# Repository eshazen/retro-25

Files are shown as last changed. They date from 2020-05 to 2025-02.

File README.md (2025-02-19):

# retro-25
Retro-tech HP-25 calculator clones using Z80

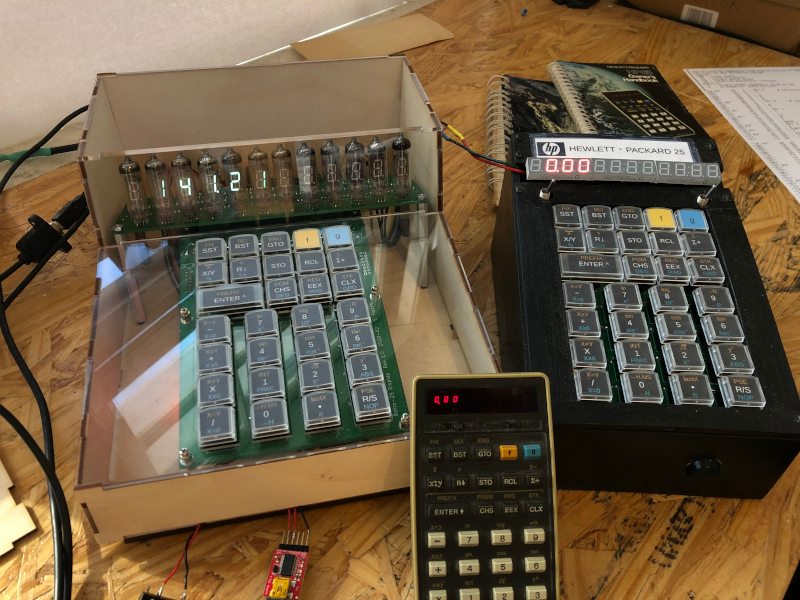
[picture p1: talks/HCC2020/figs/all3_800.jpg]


<table>
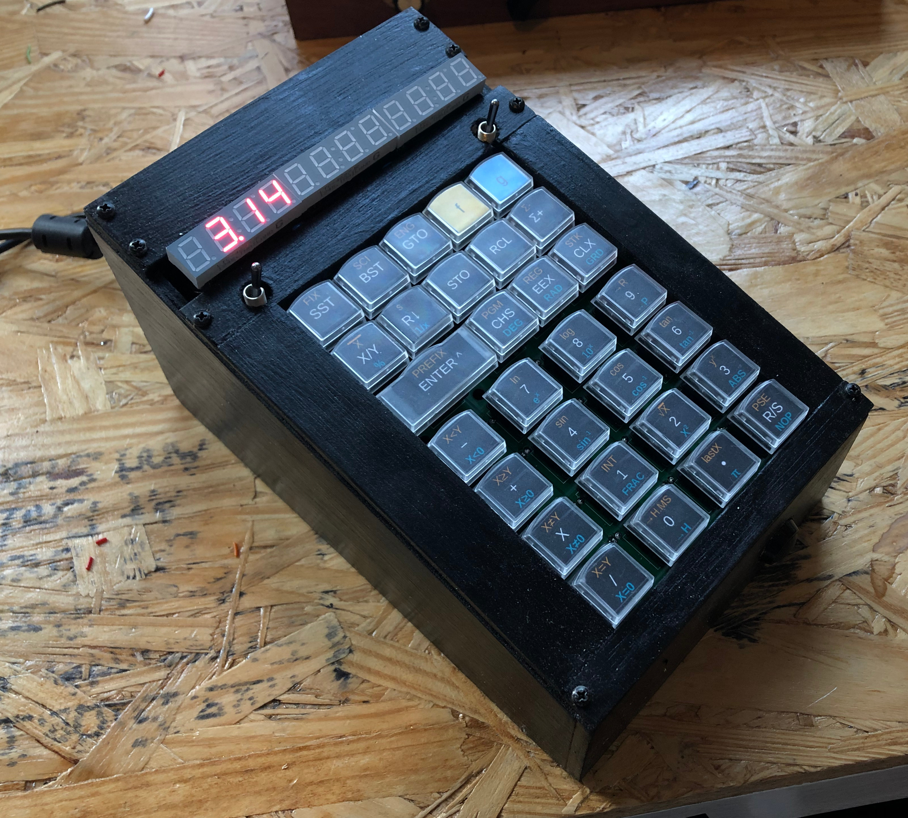
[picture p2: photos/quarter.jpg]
  <tr><td>
      <td>
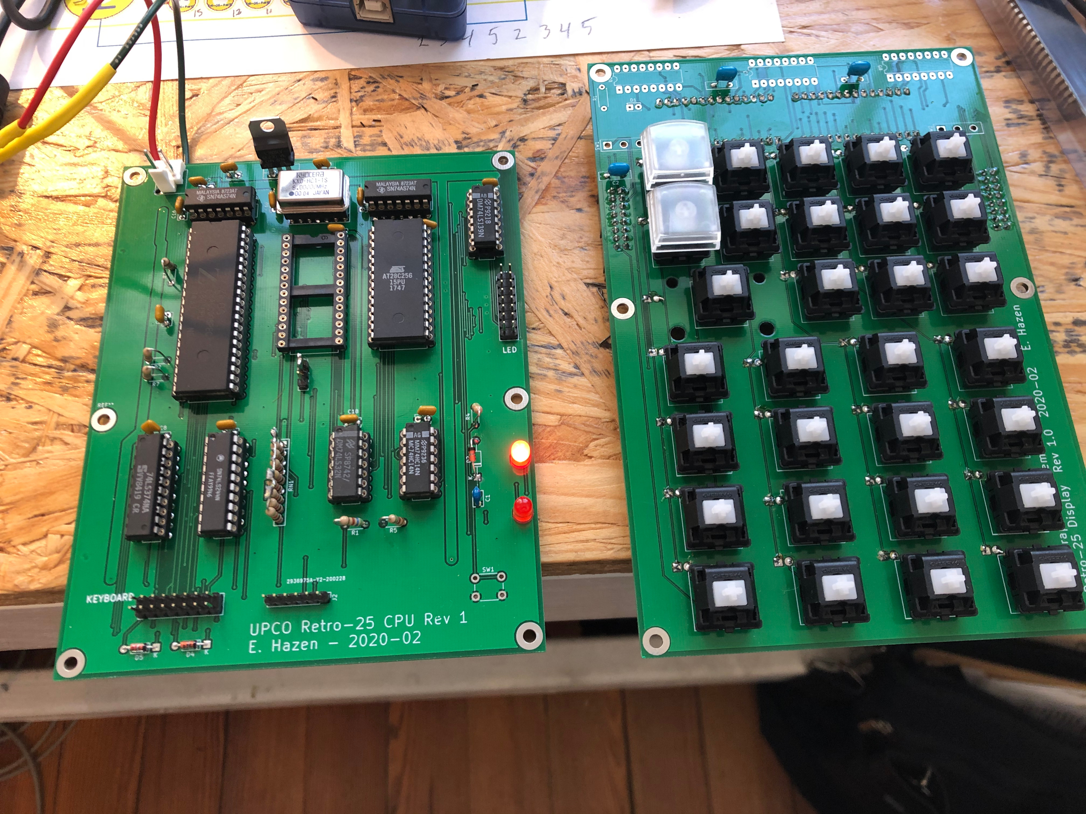
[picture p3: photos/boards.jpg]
      <td>
</table>

## News!

**2023-01-02**

This is **branch "ScopeClock"**.  Building up another CPU board for used as a general purpose computer for the scope clock, along with the DAC/Interface board from that project, which (whew!) has an actual UART for the serial port.

**2021-01-01**

Time for something new!  The VFD HP-25 is cool and all, but I've lusted after an HP-97 most of my life, plus I love nixie tubes!  Starting to think about a nixie-display HP-97 emulator.  Probably no card reader, but a small printer is certainly doable.  Inspiration from Oliver De Smet (archived elswhere in this repository just in case):

* https://www.hpmuseum.org/cgi-sys/cgiwrap/hpmuseum/archv020.cgi?read=204526
* https://sites.google.com/site/olivier2smet2/hp_projects/hp97

**2020-10-10**

I gave a talk at the HPCC 2020 conference on these calculators.  You can see my slides here:
http://www.hpcc.org/conferences/HPCC2020/HPCC2020_04_Retro_25_revC.pdf

Built a new version with VFD display tubes!

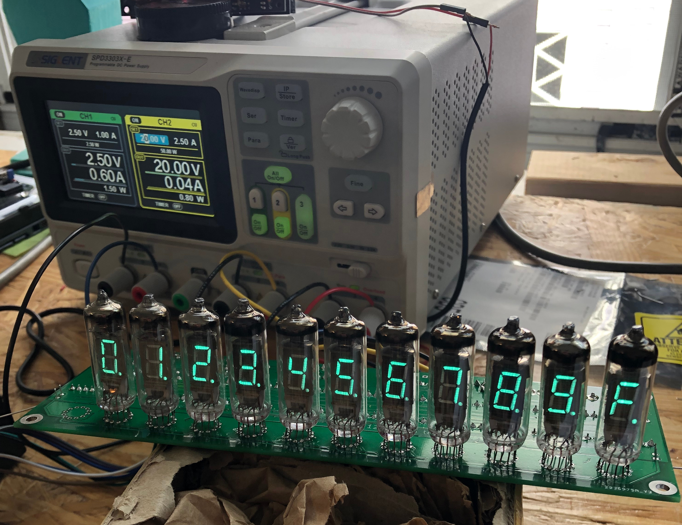
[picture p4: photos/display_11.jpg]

See <a href="https://github.com/eshazen/retro-25/tree/master/notes/VFD-Display">notes</a>.

## What's here

`hardware` has the design files for the CPU and keyboard/display boards

* `firmware/bootloader` has a small serial/flash bootloader which should be programmed at $0000
* `firmware/calc` has the main calculator operating firmware
* `firmware/umon` has a simple Z80 monitor I wrote for debugging
* `firmware/basic` has a hacked version of MS BASIC (4K integer version from 1978)
* `util` has some utility software, including: firmware loader, program loader, stack/register clip utility, simple assembler for HP-25 programs, and some template and example programs

## Hardware
The hardware consists of two boards, a CPU board and an LED+display board.

### CPU board ECOs (mistakes!)

* D2 in the reset circuit - silkscreen is backwards
* U1 pin 11 must be wired to J17 pin 11
* BUSRQ should be tied high or pulled up.  Solder a 1k resistor (or just a wire) from the Z80 (U3) pin 25 to +5V

Also, recommend to cut the trace to nWE on the EEPROM (U4, pin 27) and wire from pin 27 to pin 28.  This disables writing to the EEPROM.  Not essential, but I recommend programming the EEPROM separately in a programmer.  Rogue code can easily wear out the EEPROM (as I found the hard way!) if writing is enabled.  You have been warned.

### Memory and I/O map

The memory map is very simple:

```
EEPROM | 0000-7FFF
RAM    | 8000-FFFF
```
There are six decoded I/O ports:

port | name          | bits  | description
--- | -------------  | ----- | ---------
00 | KB (write only) | bit 0 | KB column 1
"   | "                | bit 1 | KB column 2
"   | "                | bit 2 | KB column 3
"   | "                | bit 3 | KB column 4
"   | "                | bit 4 | KB column 5 and switches
"   | "                | bit 5 | -not used-
"   | "                | bit 6 | LED on CPU board
"   | "                | bit 7 | Serial output
40 | Digits 0-7      | bits 0-7 | ICM7218 display data
41 | Digits 0-7      | bits 0-7 | ICM7218 control data
80 | KB (read only)  | bit 0 | KB row 1
"   | "                | bit 1 | KB row 2
"   | "                | bit 2 | KB row 3
"   | "                | bit 3 | KB row 4
"   | "                | bit 4 | KB row 5
"   | "                | bit 5 | KB row 6
"   | "                | bit 6 | KB row 7
"   | "                | bit 7 | Serial input
c0 | Digits 8-11     | bits 0-7 | ICM7218 display data
c1 | Digits 8-11     | bits 0-7 | ICM7218 control data

All ports except `80` are write-only; port `80` is read-only.

A bit-banged serial port using an FTDI USB adapter is provided
as bit 7 of ports `00` and `80`.  Note that these ports share
keyboard scanning functions, so the code must be carefully written
if both functions are used simultaneously.

There are no interrupts.

## Firmware

See `firmware/calc` for calculator operating program

See `util` for assembler and loader utilities

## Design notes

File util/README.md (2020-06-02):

# Utility software

This folder contains some utility software which runs on a PC connected to the Retro-25.

## Assembler

`asm25.pl` is a simple assembler for HP-25 code.  It reads input files like this:

```
#
# very simple example:  count by 1's
#
count.txt
 1  : ENTR
 2  : 1
 3  : +
 4  : PSE
 5  : GTO 01
 6  : GTO 00     # always end with GTO 00
```

It produces a listing file:

```
count.lst
"31"       f6   1  : ENTR
"01"       c1   2  : 1
"51"       f1   3  : +
"14 74"    d5   4  : PSE
"13 01"    01   5  : GTO 01
"13 00"    00   6  : GTO 00
"13 00"    00   7  : GTO 00
```

And a hex file
```
f6c1f1d5010000
```

## Program Loader

`load_prog.c` is a C program to load HP-25 programs assembled with `asm25.pl` to the calculator.  For example:

```
  $ ./load_prog /dev/ttyUSB0 P `cat count.hex`
```

## Firmware Loader

`load_firmware.c` is a C program to overwrite the operating firmware
in the calculator with a new version.  Note that at the moment there
is no ability to program the flash, so this is temporary until the next power-cycle, at which
point the calculator will revert to the EEPROM version.

```
  # (push reset button, then within ~10 sec:)
  $ ./load_firmware ../firmware/calc/main-9000.hex /dev/ttyUSB0
```

The loader assumes that a bootloader like `ser_19200_boot.asm` is running and has been put in the 
boot state by pressing reset.  It would be sensible to include the serial bootloader in the calculator code itself,
but I haven't gotten around to this yet.

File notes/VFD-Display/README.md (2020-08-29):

# VFD display

<table>
  <tr><td>
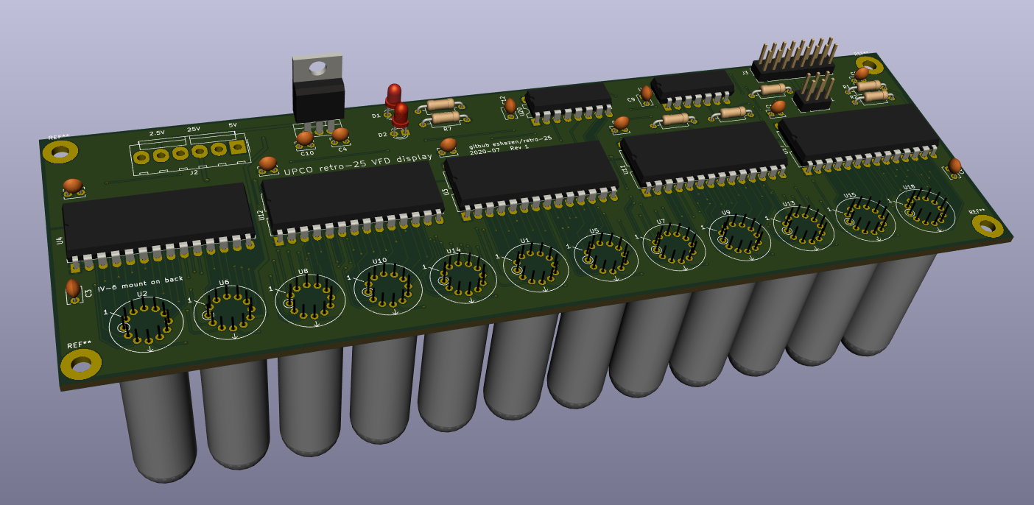
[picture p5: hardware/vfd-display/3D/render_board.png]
    <td>
    <td>
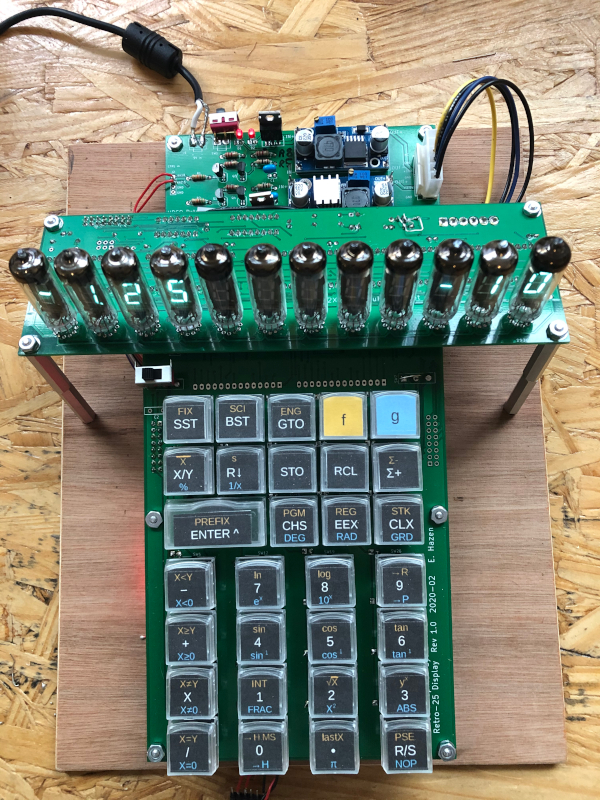
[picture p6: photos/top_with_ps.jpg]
  <tr><td>
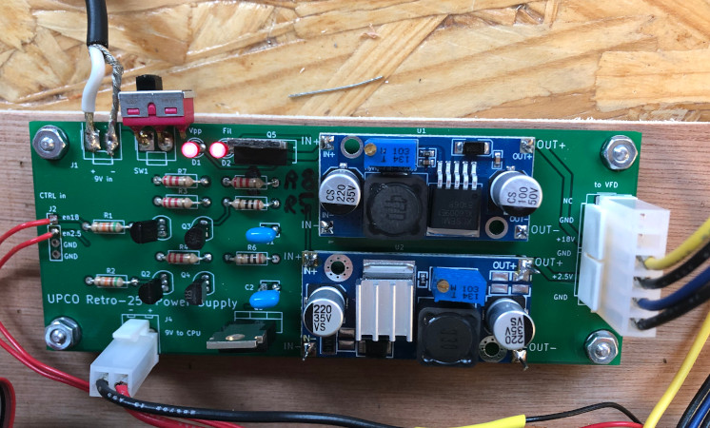
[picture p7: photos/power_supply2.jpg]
    <td>
</table>

## Progress!

_8/29/20_

Installed new power supply board.  This board provides +18V for VFD
anodes and +2.5V for VFD filaments (regulated to 1.25V on the display
board itself).  Each output is switchable and controlled by the Z80.
This is so that the tubes can power down after a timeout to extend
their life.

_8/12/20_

Finally have all 12 tube installed plus 5 spares.  Calculator software runs!  Key caps in hand.  Designed and ordered a plywood+acrylic box from Ponoko, parts due 9/1/20.

Software status:

* EEPROM has ```umon``` at 8100H
* Calculator builds for VFD if ```VFD``` is defined in ```Makefile```.
* Load with ```L``` command in ```umon```, then 
```
  $ ../../util/load_firmware main-9000.hex /dev/ttyACM0
```

_8/2/20_

Tubes arrived from Kiev after about 5 weeks, but one is missing a pin.  Ordered another batch of 6 so I have some spares.  Assembled the display board and connected to an Arduino for testing.  It works!  Some segments are a bit dim, but at 20V everything seems ok. Power measure below

Voltage | Current | Notes
------- | ------- | -----
  2.5V  |   0.6A  | Filaments (reg to 1.2V)
  5.0V  |   0.03A | Logic (comes from CPU board)
 20.0V  |   0.6A  | Grids
  9.0v  |  ~1.6A  | 1.6A no LEDs, "0.00" = 2.3A, 8's = 3.8A
  
Need a power supply.  Features:  power-up sequence:  (1) 2.5V and 5V(9V) on, delay  (2) 20V on.  Reverse for power-down.  20V should be easily adjustable by the user, and should be controlled by CPU or a timer so it goes off to save the tubes.  After a longer delay the filaments should power down.

Ordered some XL6009 boost modules which should do the job for the 20V.  Would want to add an enable and remote the voltage adjust pot.  Assuming 80% efficiency, need 1.6A at 9V to power, plus CPU at ~1.6A is 3.2A.  Possibly the "2A" 9V converters we have would work, since the VFD display uses about the same power as the LEDs.

Have an LM2586 buck module.  No external enable but looks as if one could unsolder the enable pin and add a wire.

The two LED outputs on the VFD board could be used to control the filament and grid supplies, making for a self-contained unit.

Need to build a breadboard or PCB thing to hold the boost and buck converters and the connectors for power.

_7/2/20_

PCB design created under ```hardware/vfd-display```.  Plugs in to display connector on CPU.  Includes 5 HV5812 drivers for 12 digits of VFD, 2 LEDs and 3 jumper/switch/GPIO inputs.  Buffered/latched from the CPU bus.  Ordered from JLCPCB on 7/2/20.  Delivered 7/9/20.  Quick service!

## Notes

I've been thinking about a Nixie tube version of an HP calculator
clone for a while, but there are a few problems:  need a 180V power
supply, no decimal point or sign options.

A nice intermediate but still retro option is VFDs, which are very
cheap, 7-segment, include a decimal point and are easier to drive
(they need 20-25V and low-voltage filament power).

I think I can re-use the keyboard part of the keyboard/display,
shearing off the display part (dotted in the drawing) and stack the
CPU board directly below.  There would be a new roughly 200x50mm
display board with (4) HV5812 driver chips.  These are really nice,
having a serial interface and 20 HV output drivers in a friendly DIP28.

The tubes would project vertically up from the new board, which would
be mounted at a nice viewing angle.

There are a few issues:

* Need a 25V supply, but << 1A total current
 * Ordered an MT3806 boost module "free" ship from China.  Also need a buck to provide 2.5V or so for the filaments.  Maybe a PS sequencing circuit, as the HV should come on last and turn off first.
* Need to power the filaments at 1.2V each, 50mA (total 0.6A if parallel,
or 14.4V if series).

Driving the long shift register with 96 segments is easy and could be
done directly by the Z80.

<a href="https://github.com/eshazen/retro-25/blob/master/notes/VFD-Display/new-pcb-top-view.png">
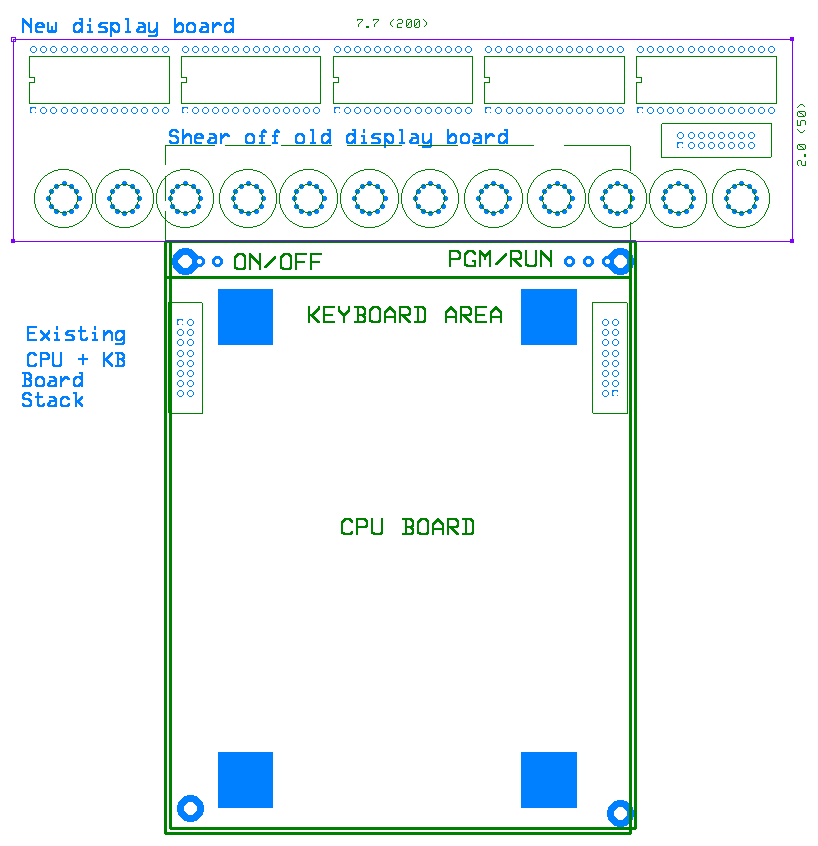
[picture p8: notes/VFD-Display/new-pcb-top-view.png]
  
  <br>Sketch of the idea</a>

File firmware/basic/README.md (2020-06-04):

Just for fun, this is a version of Microsoft BASIC 4.7 modified to run
on the calculator.  Originally for NASCOM computers, modified by
Grant Searle for his "7-chip Z80 computer" (see http://searle.wales).
Further modified by me to work with the bit-bang serial interface on
the Retro-25.

Memory info (Grant's version):

`int32k.asm` is a small monitor which handles the serial port
and basic initialization.  `bas32k.asm` is the BASIC interpreter.
```
-------------------- int32k memory --------------------

  0000       DI
             JP     INIT      ; 00B8
  0008       JP     TXA       ; RST08 - serial TX
  0010       JP     RXA       ; RST10 - serial RX
  0018       JP     CKINCHAR  ; RST18 - check serial status
  0038       JR     serialInt ; RST38 - hardware interrupt
  
  003A serialInt:
  0074 RXA:
  009F TXA:
  00AA CKINCHAR:
  00B0 PRINT:   ; print a string
  
  00B8 INIT:  ; initialize serial, print message, jump to either
              ; $150 (cold) or $153 (warm)
			  
  0144 END
  
  8000 serBuf       ; serial buffer of 3FH bytes
  803F
   ...              ; other local variables
  8044   
  
  80ED TEMPSTACK    ; temporary stack location
  
  -------------------- BASIC memory map --------------------
  
  0150 ORG
  0150          JP STARTB
  0153          JP WARMST
  0156 STARTB:  LD IX,0
                JP CSTART
				...
  0160 CSTART:  LD HL,WRKSPC   ; copy init table to 8045H
                LD B,INITBE-INITAB+3
				LD DE,INITAB
	   COPY:    ...
	   
```

Strategy for porting BASIC:

Code runs from 0150 to 1DB3

Include serial I/O code 
Load the code starting at 8150H so currently would end at 9DB3 (plus serial code)

Apparently the only thing needed to change for RAM size is WRKSPC, as in
Grant's version the 56K BASIC has `WRKSPC .EQU 2045H` and the 32K BASIC has
`WRKSPC .EQU 8045H`.

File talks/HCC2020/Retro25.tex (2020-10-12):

%------------------------------------------------------------
% Retro-25 calculators
%------------------------------------------------------------

\pdfminorversion=4   % fix Acrobat error
\documentclass{beamer}
\usepackage{graphicx}
\usepackage{tikz}    % for logo onlyh
\usepackage{xcolor}
\usepackage{hyperref}
\usepackage[absolute,overlay]{textpos}
\usepackage{makecell}
\usepackage{array}
\usepackage{makecell}
\usepackage{fancyvrb}

\definecolor{my-red}{RGB}{128,0,0}
\definecolor{my-green}{RGB}{0,96,0}
\definecolor{my-blue}{RGB}{0,0,128}
\definecolor{my-orange}{RGB}{160,83,0}
\definecolor{my-violet}{RGB}{142,0,209}
\definecolor{my-aqua}{RGB}{0,96,96}
\definecolor{my-olive}{RGB}{89,124,0}

\newcommand{\tred}[1]{\textcolor{my-red}{#1}}
\newcommand{\tgreen}[1]{\textcolor{my-green}{#1}}
\newcommand{\tblue}[1]{\textcolor{my-blue}{#1}}
\newcommand{\torange}[1]{\textcolor{my-orange}{#1}}
\newcommand{\tviolet}[1]{\textcolor{my-violet}{#1}}
\newcommand{\taqua}[1]{\textcolor{my-aqua}{#1}}
\newcommand{\tolive}[1]{\textcolor{my-olive}{#1}}

\renewcommand{\indent}{\hspace*{2em}}
\renewcommand{\arraystretch}{1.5}

\usepackage{hyperref}
\hypersetup{
    colorlinks=true,
    linkcolor=blue,
    filecolor=magenta,      
    urlcolor=cyan,
}
 
\urlstyle{same}

\begin{document}

\hypersetup{urlcolor=my-blue}
\urlstyle{tt}

% Add footer text
\addtobeamertemplate{footline}{
  \parbox{\linewidth}{\vspace*{-8pt}
    ~~~ Slide \insertframenumber/\inserttotalframenumber
    ~~~ 2020-10-10 ~~~
    Eric~Hazen
}
}

% Move footnotes above footline
\addtobeamertemplate{footnote}{}{\vspace{0.1in}}

% add BU + ATLAS logo
\addtobeamertemplate{frametitle}{}{%
\begin{tikzpicture}[remember picture,overlay]
\node[anchor=north east,yshift=2pt] at (current page.north east)
%{\includegraphics[height=0.8cm]{figs/BU_LOGO.png}};
{};
\end{tikzpicture}}

\title{The Retro-25 DIY Calculators}
\date{2020-10-10 RevB}
\author
{
  \begin{center}
     \\
%   \includegraphics[height=3cm]{figs/led_front.jpg} 
%   \includegraphics[height=3cm]{figs/vfd_over.jpg}
   \end{center}
\scriptsize
 Eric~Hazen \\
\tblue{from (but not representing) Boston University}
}

\newcommand{\spage}[1]{
\begin{frame}
  \begin{tikzpicture}[remember picture, overlay]
  \node[anchor=north]at(current page.north){
     
  };
  \end{tikzpicture}
\end{frame}
}
%% 
%% %---------- Title
\frame{\titlepage}

\begin{frame}
  \frametitle{Personal and Professional History...}
  \vskip -0.2in
  
  \begin{tabular}{p{0.7\textwidth}c}
  \scriptsize
  I've been fascinated by electronics since I was very young! & \\
    \scriptsize
    At age 13 (in 1973) I lived briefly in Leeds, England and worked
    at the Uni as an unpaid physics ``graduate assistant''.
    I encountered an HP-9100 and
    taught myself to program it.  I was immediately hooked! &
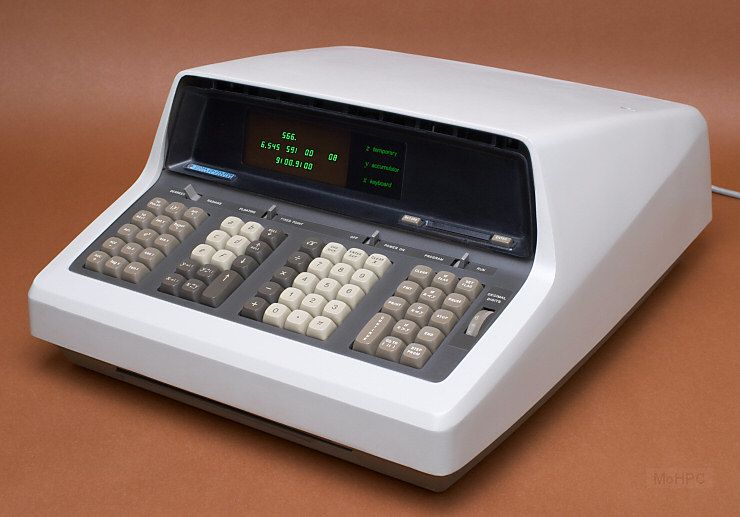
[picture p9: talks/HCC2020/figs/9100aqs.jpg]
    \raisebox{-0.6\height}{} \\
  \scriptsize
  In High School I made the acquaintance of an HP-2100 series
  computer running HP timeshare BASIC.  We played various games
  (some legit, like TREK73) and others (posting the administrator password
  on the chalkboard) not so legit.  &
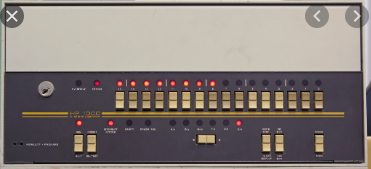
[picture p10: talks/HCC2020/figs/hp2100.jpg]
    \raisebox{-0.8\height}{} \\
    \scriptsize
    In 1975 my father bought an HP-25.
    I devoted myself to delivering the {\em Ann Arbor News}
    faithfully to about 60 subscribers, and eventually I could afford my
    own HP-25 at \$195.00 (about \pounds 663 today) &
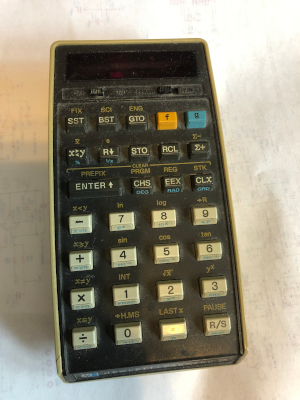
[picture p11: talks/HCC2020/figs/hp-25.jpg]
    \raisebox{-0.6\height}{} \\
    \scriptsize
    Unfortunately my HP-25 is dead; it fell in the fish tank with
    the piranhas while I was away and my roomies were scared to
    retrieve it!  My father's is in my posession and still working! &
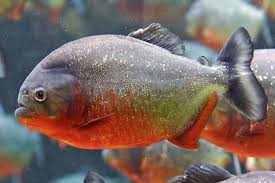
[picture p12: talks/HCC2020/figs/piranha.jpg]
    \raisebox{-0.6\height}{} \\    

  \end{tabular}
\end{frame}

\begin{frame}
  \frametitle{...more history}
  \vskip -0.2in

  \begin{tabular}{p{0.7\textwidth}c}
  \scriptsize
  I studied computer science for a while at Michigan and
  became expert with the model 29 keypunch (I hated that thing!)
  I did learn a few other things (ALGOL and S/370 assembly) &
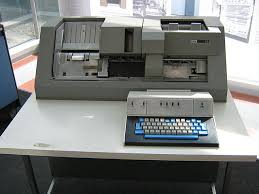
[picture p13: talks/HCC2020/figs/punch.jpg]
    \raisebox{-0.8\height}{} \\
  \scriptsize
  What really changed my life was working at Radio Shack.
  They introduced the TRS-80 and I immediately bought one
  (well, honestly, I put it on ``lay-a-way'' at my house!)
  I taught myself Z80 assembly language and wrote a simple multi-tasking
  kernel and FORTH system. &
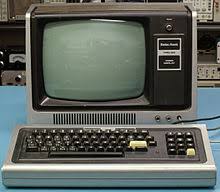
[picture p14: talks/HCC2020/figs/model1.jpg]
    \raisebox{-0.8\height}{} \\  
  \scriptsize
  I parlayed my Z80 skills into a job at ETC (theatre lighting).
  I designed their Idea$^{TM}$ and Vision$^{TM}$ lighting consoles, and wrote
  much of the low-level software in Z80 assembly (using my trusty
  TRS-80, now decked out with dual 8 inch floppies) as a dev system. &
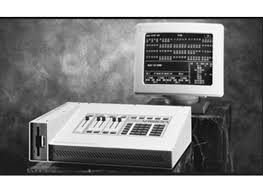
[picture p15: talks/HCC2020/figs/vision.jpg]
    \raisebox{-0.8\height}{} \\    
    \scriptsize
  Since then I've worked at Boston University building electronics
  mostly for the LHC at CERN.
  I've also become somewhat of an HP collector, acquiring a 10C,
    11C, 15C, 16C and 67.  The 10C and 15C were filched, the 11C and 16C
    I use almost daily.
&
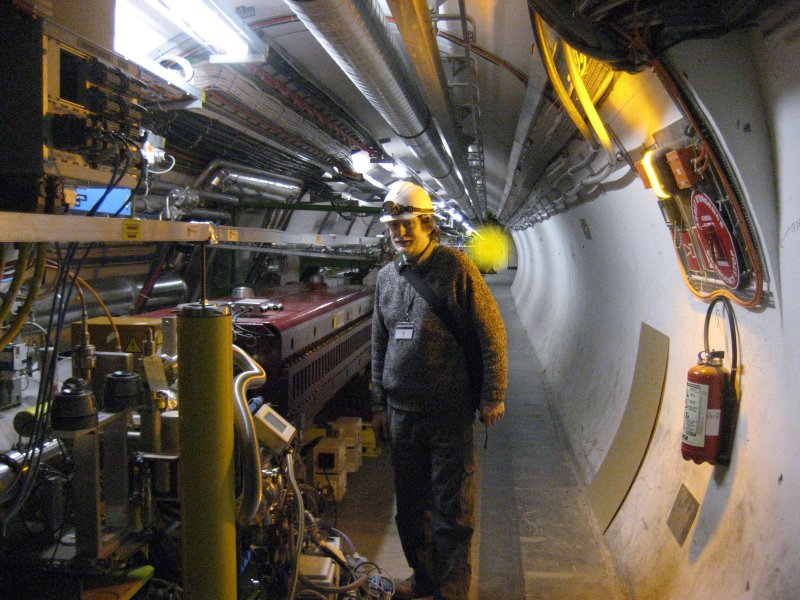
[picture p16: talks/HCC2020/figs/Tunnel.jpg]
  \raisebox{-0.8\height}{} \\    
  \end{tabular}
\end{frame}

\begin{frame}
  \frametitle{Why? Why? Why?}

  \begin{columns}
  \column{0.7\textwidth}
  \tblue{Why a DIY HP-25?}

    \begin{itemize}
    \scriptsize
    \item The HP-25 is my favorite calculator
    \item The display and keyboard are too small for middle-aged eyes
    \item I hate mouse- and touchscreen-based emulators \\ (no tactile feel)
    \item I have a bunch of time on my hands ({\em NOT!})
    \end{itemize}
    \vskip 0.1in
  
    \tblue{Why use a Z80?}
  
    \begin{itemize}
    \scriptsize
    \item I know them inside-out
    \item They were released about when the HP-25 came out
    \item I like designing and assembling good old thru-hole DIP boards
    \end{itemize}
    \vskip 0.1in
  
    \tblue{Why the HECK VFD displays?}
    \begin{itemize}
    \scriptsize
    \item Because they are {\em cool!} \\
     (and nixies are a lot of trouble)
    \end{itemize}

  \column{0.3\textwidth}

    
    \vskip 0.1in
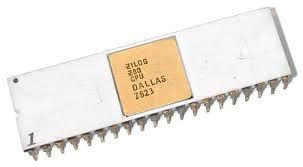
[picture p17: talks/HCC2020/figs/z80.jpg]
    
    \vskip 0.3in
    

  \end{columns}
\end{frame}

\begin{frame}
  \frametitle{Specification}

  Well, this is a hobby project so no spec needed, but I had goals:
    \begin{itemize}
    \item Big, clicky buttons; display I can read without glasses
    \item Simple hardware I could solder easily
    \item Cross-development from my Linux machine
    \end{itemize}

\end{frame}

\begin{frame}[shrink=5]
  \frametitle{Parts! Parts! Parts!}

  \vskip -0.15in
  \tgreen{I always start with the parts.}

    \scriptsize
  \begin{tabular}{p{0.7\textwidth}c}
    CPU: The Z80 is a no-brainer (initially Z80A, 4MHz) & 
     \raisebox{-0.5\height}{} \\
     \hline
     \makecell[l]{Memory: first considered UV EPROM (nah!) \\
    AT28C256-15 EEPROM and 62256LP-70 RAM (both 32k, DIP-28)} & 
     \raisebox{-0.5\height}{} \\
     \hline
     \makecell[l]{Display: \\ 
                        V1: 10mm red 10mm red common anode 7-segment \\
                        V2: IV-6 green vacuum fluorescent display tubes}
     &
     \raisebox{-0.5\height}{} \\
     \hline
    Driver:  ICM7218A MUX driver.  I used these for
    theatre lighting consoles back in the day and they work well. & 
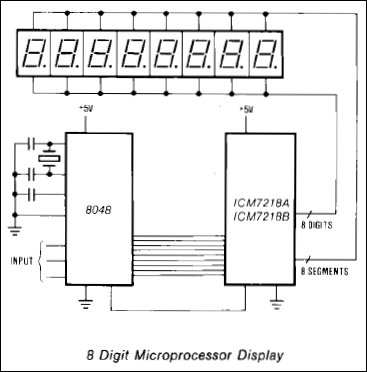
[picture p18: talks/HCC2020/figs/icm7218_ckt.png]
     \raisebox{-0.5\height}{} \\
     \hline
    Switches:  Cherry MX1A mechanical.  These are my favorites! &
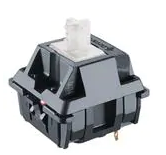
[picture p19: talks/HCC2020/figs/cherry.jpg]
     \raisebox{-0.3\height}{} \\
     \hline
  \end{tabular}

  \vskip 0.15in
  Otherwise, I have drawers full of 74LS and 74S series TTL at work
  because we can't bear to throw anything....

\end{frame}

\begin{frame}
  \frametitle{Boards!}

  \scriptsize
  How many boards?  Started with a ``toy'' layout in ExpressPCB to
  see how everything fit.  Looked like about 120x170mm.  So, I fired
  up KiCAD and made a schematic and did a layout for a Display/Keyboard.

  \vskip 0.15in

\begin{columns}
\column{0.33\textwidth}
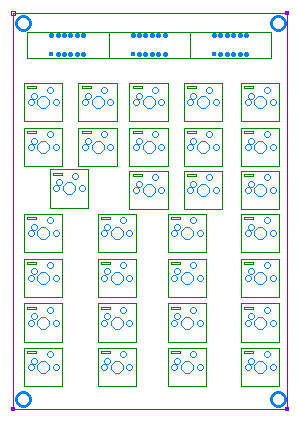
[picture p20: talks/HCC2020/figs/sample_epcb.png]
  
\column{0.33\textwidth}
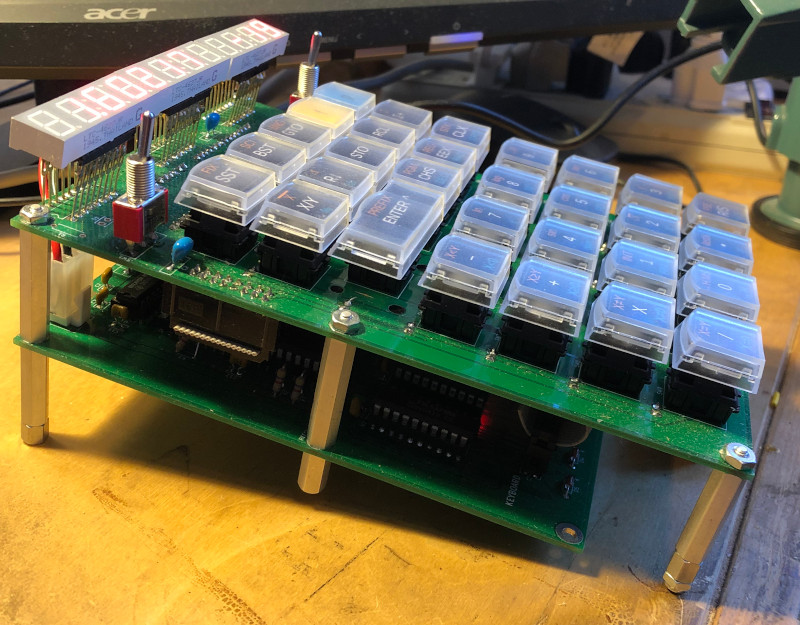
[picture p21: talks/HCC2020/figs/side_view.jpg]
   
\column{0.33\textwidth}
    \begin{itemize}
    \scriptsize
    \item Doesn't look like the CPU etc will fit
    \item Planning for a two-board stack
    \end{itemize}
\end{columns}

\end{frame}

\begin{frame}
  \frametitle{Schematics (KB, Display)}  

  \vskip -0.2in
  

  \scriptsize
  \begin{columns}
  \column{0.5\textwidth}
  \tblue{Keyboard is standard matrix}
  \column{0.5\textwidth}
  \tred{Display handled by two ICM7218A.  \\ Almost no additional parts}
  \end{columns}
\end{frame}

\begin{frame}
  \frametitle{PCB (KB, Display)}

  \vskip -0.2in
  \scriptsize
  \begin{columns}
  \column{0.5\textwidth}
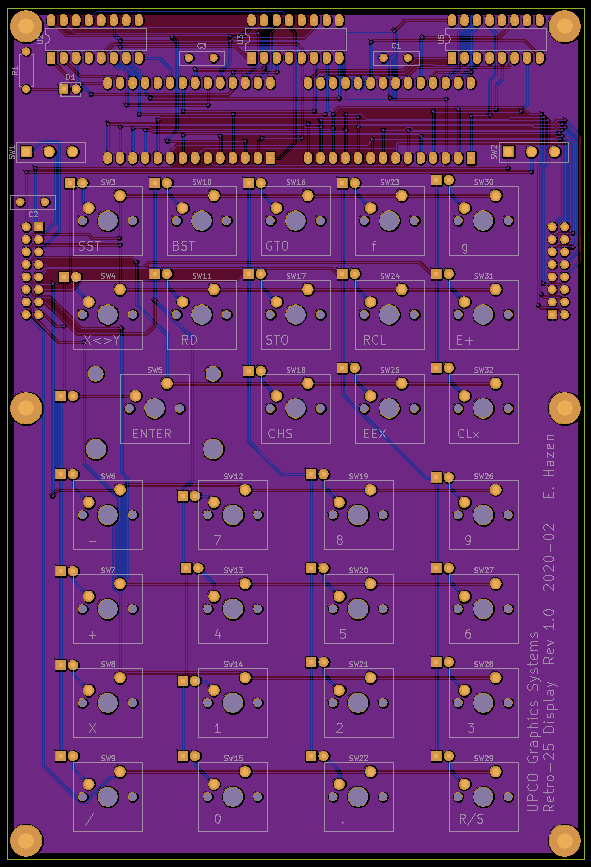
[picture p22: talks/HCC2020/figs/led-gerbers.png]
            
  \column{0.5\textwidth}
  
    Placement and routing pretty simple. \\
    Two header connectors, one for KB and one for LEDs
    \vskip 0.1in
    \tviolet{Top Cu area to GND} \\
    \tred{Bottom Cu area to VCC} \\
    \vskip 0.1in
    Design rules based on what JLCPCB could do easily: \\
    \tgreen{
    ~~ 6 mil line/space (0.15 mm)\\
    ~~ 20 mil via with 10 mil hole \\ ~~~~(0.5mm / 0.25mm)} \\
    \vskip 0.1in

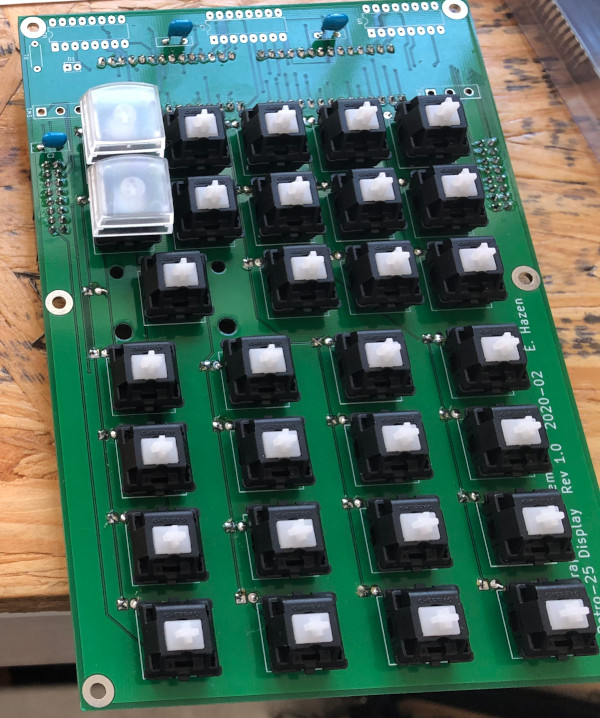
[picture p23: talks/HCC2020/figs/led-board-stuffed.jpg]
    

\end{columns}
\end{frame}

\begin{frame}
  \frametitle{Schematics (CPU)}

  \vskip -0.2in
  

\end{frame}

\begin{frame}
  \frametitle{PCB (CPU)}

  \vskip -0.2in
  \scriptsize
  \begin{columns}
  \column{0.5\textwidth}
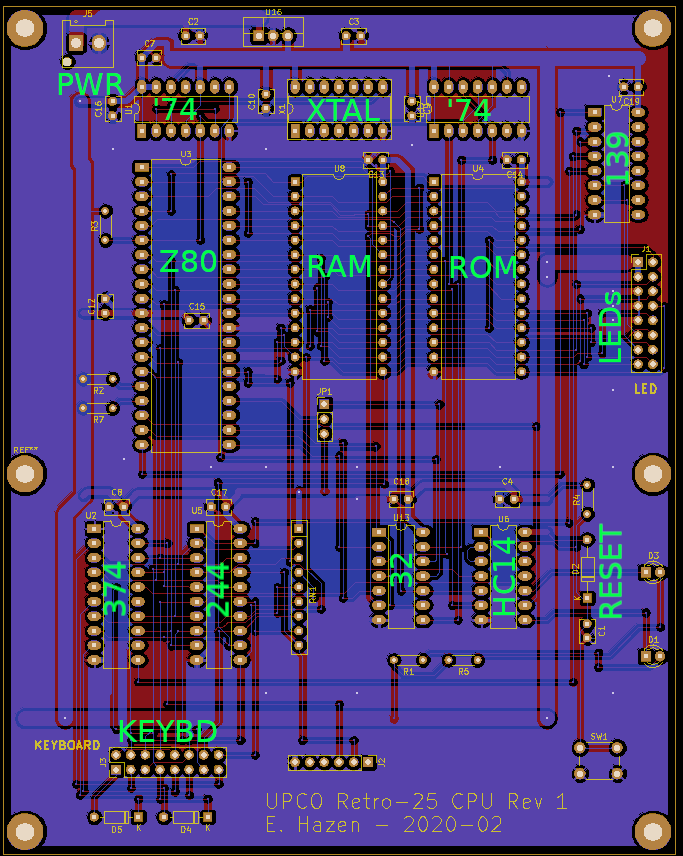
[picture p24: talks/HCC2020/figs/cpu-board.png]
    
  \column{0.5\textwidth}
  
    Placement and routing pretty simple. \\
    Two header connectors, one for KB and one for LEDs \\
    All components on the top.
    \vskip 0.2in
    \tviolet{Top and bottom Cu areas to GND} \\
    \vskip 0.2in
    \tblue CPU, RAM, EEPROM in top row
    \vskip 0.2in
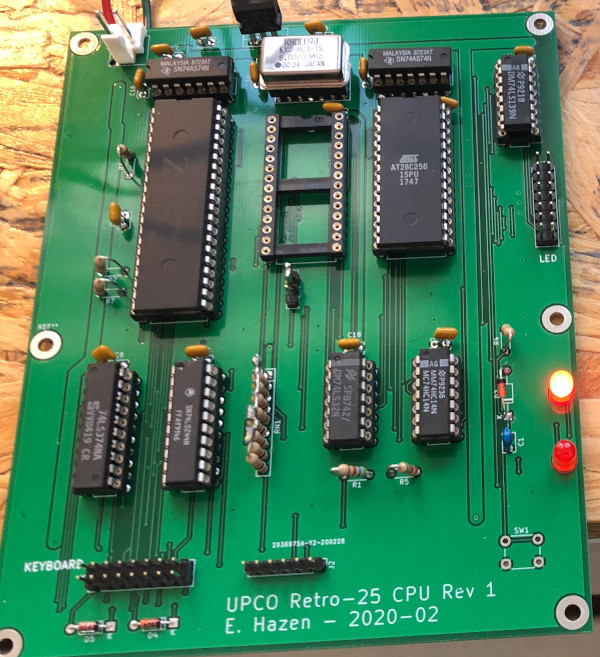
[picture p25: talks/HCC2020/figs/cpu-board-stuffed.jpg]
    
\end{columns}
\end{frame}

\begin{frame}
  \frametitle{Bringing it Up! (hardware)}
  \begin{columns}
  \column{0.5\textwidth}
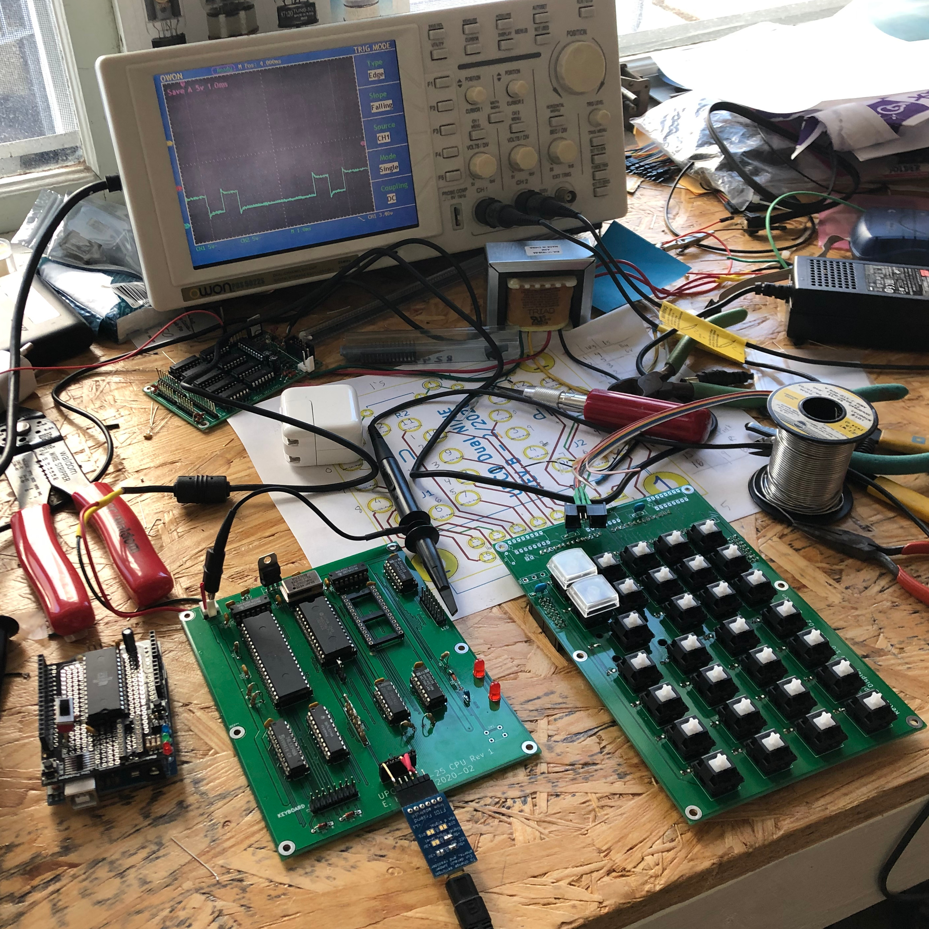
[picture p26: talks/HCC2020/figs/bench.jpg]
    
  \column{0.5\textwidth}
    \tgreen{The boards and parts are here!}
    \begin{itemize}
    \scriptsize
    \item Easy soldering (all thru-hole) \\
      But then what?  Software?
    \item Brief diversion to make a junk-box EEPROM programmer
    \item First program:  delay, then HLT \\
       i.e. {\tt 2B 7C B5 20 FB 76} \\
       (glad I put a HALT LED on the board!)
    \item Then a struggle with bit-bang serial \\
       (next time use a UART!)
    \item Then write a debug monitor... ``umon2''.
    \end{itemize}
    \tred{Two months later...}
\end{columns}
\end{frame}

\begin{frame}[shrink=10]
  \frametitle{Bringing it Up!  (software)}
  \begin{columns}
  \column{0.5\textwidth}
    \scriptsize
     \\
    \url{http://nonpareil.brouhaha.com} \\
    \vskip 0.1in
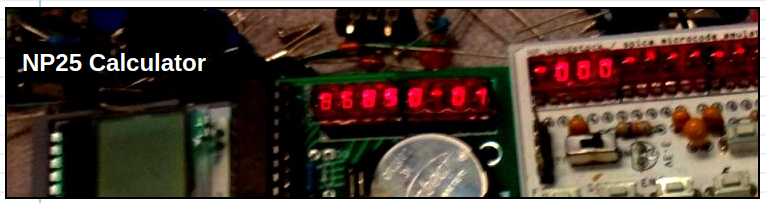
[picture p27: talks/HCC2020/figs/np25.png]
     \\
    \url{http://simpleavr.github.io/NP25/} \\
    \vskip 0.1in
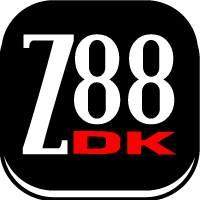
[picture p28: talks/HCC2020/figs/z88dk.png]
     \\
    \url{https://github.com/z88dk/z88dk}
    \vskip 0.1in
     \\
    \url{https://www.autometer.de/unix4fun/z80pack/}
  \column{0.5\textwidth}
    \tgreen{Download and study...}
      \begin{itemize}
      \scriptsize
      \item Nonpareil by Eric Smith \\
        Very complete, but quite complex as it supports
        many models
      \item NP25 ``Nonpareil Physical'' by Chris Chung \\
        Woodstock-only emulator for MSP430 \\
        Much more promising
      \end{itemize}
    \scriptsize

    \vskip 0.1in
    \tblue{In the end I took some of both, and got an HP-25 only
      simulation running in plain C under linux, using a tty
      for input and output.} \\

    \vskip 0.1in
    \tviolet{Then, I built it using {\tt sdcc} in Z88DK and tested
      it under the {\tt z80pack} simulator.}
%    \tgreen{
  \end{columns}
\end{frame}

\begin{frame}[fragile]
  \frametitle{Bringing it Up!  (hardware+software)}

  \begin{columns}
  \column{0.75\textwidth}
  \scriptsize
  \vskip -0.2in
  \tgreen{Lots of loose ends...} \\
  \vskip 0.1in
  \tblue{First, write a serial boot loader} \\
  \vskip 0.1in
  \tblue{Then write a C program to send hex files} \\
  \vskip 0.1in
  \tblue{Then, work on the monitor...} \\
\begin{Verbatim}[fontsize=\tiny]
  d <addr> <count>         dump memory
  e <addr> <dd> <dd>...    edit up to 16 bytes in memory
  o <port> <val>           output <val> to <port>
  z <val>                  set port zero value bits 0-6
  i <port>                 input from <port> and display
  g <addr>                 goto addr
  b <addr>                 set breakpoint (currently 3-byte call)
  a <val1> <val2>          hex Arithmetic
  c                        continue from breakpoint
  c <addr>                 continue, set new breakpoint
  m <start> <end> <size>   memory region compare
  p <start> <end> <size>   memory region copy
  l                        binary load from serial
  r                        repeat last command
  k                        scan HP keyboard
  f <addr>                 dump HP registers from <addr> (A)
  7 <addr>                 update 7-segment display from <addr>
  V <addr>                 update VFD display from <addr>
\end{Verbatim}
  \tred{I eventually needed all of those commands...} \\
  \vskip 0.1in
  \tgreen{Finally, start to load and debug the calculator} \\
  \tgreen{Before long, it works!!}
  \column{0.25\textwidth}

  

  \end{columns}
\end{frame}

\begin{frame}
  \frametitle{Wrapping it Up}
  \framesubtitle{}
  \begin{tabular}{cp{0.5\textwidth}{c}}
    \raisebox{-0.6\height}
      {} &
    \scriptsize
    Stack the boards, add ``on/off'' and ``prgm/run'' switches,
    Make a simple wood box, it's done!
    \\
     &
     \\
  \end{tabular}
\end{frame}

\begin{frame}
  \frametitle{What Next?}
  \framesubtitle{S/N 2, of course!}

  \scriptsize

  \begin{columns}
  \column{0.3\textwidth}
    \tgreen{LEDs are boring! \\ Nixies are troublesome!} \\
    \vskip 0.1in
    \tred{Let's try VFDs... never used them before} \\
    \vskip 0.5in
    
  \column{0.75\textwidth}
    \tblue{My Russian isn't so good, but Google Translate to the rescue...} \\
    \vskip 0.2in
    
    
  \end{columns}
\end{frame}

\begin{frame}
  \frametitle{VFD Display Board}
  \framesubtitle{Schematic}
  
\end{frame}

\begin{frame}
  \frametitle{VFD Display Board}
  \framesubtitle{PCB Design}
  \vskip -0.2in
  \begin{columns}
  \column{0.6\textwidth}
     \\ 
    \vskip 0.4in
     \\
  \column{0.5\textwidth}
    \begin{itemize}
    \scriptsize
    \item 12 display tubes
    \item 5 HV5812 driver chips
    \item 2 TTL chips
    \item 1.2V @ ~1A for filaments
    \item Power connector (5V, 2.5V, 20V)
    \item Ribbon cable compatible with LED board
    \item Two layer, pretty simple layout
    \item Fun with 3D modeling!
    \end{itemize}
    \vskip 0.1in

    

  \end{columns}
\end{frame}

\begin{frame}
  \frametitle{VFD Power Supply}
  \vskip -0.2in
    
\end{frame}

\begin{frame}
  \frametitle{VFD Power Supply}

  \begin{columns}
  \column{0.5\textwidth}
   \\
  \vskip 0.2in
  
  \column{0.5\textwidth}
    \begin{itemize}
    \scriptsize
    \item Use Buck / Boost modules from China
    \item Simple switching logic to control from Z80
    \item Add a power switch for the whole unit
    \end{itemize}
  \end{columns}
\end{frame}

\begin{frame}
  \frametitle{Putting it All Together}

  \begin{columns}
  \column{0.5\textwidth}
    
    \begin{itemize}
    \scriptsize
    \item Test the display using an Arduino
    \item Integrate the VFD code
    \item It works!
    \end{itemize}
  \column{0.5\textwidth}
     \\
  \end{columns}
\end{frame}

\begin{frame}
  \frametitle{Summary, Extras}

  \begin{columns}
  \column{0.5\textwidth}
    \begin{itemize}
    \scriptsize
    \item I've built two HP-25 replicas using Z80 CPUs
    \item One with 10mm LEDs, one with IV-6 VFDs
    \item Both run HP-25 microcode at normal speed
    \end{itemize}
    \vskip 0.2in
    \scriptsize
    I currently have no plans to sell kits or finished
    units, but all documentation and firmware are here:
    \url{https://github.com/eshazen/retro-25}

  \column{0.5\textwidth}
    
    \vskip 0.2in
    
  \end{columns}
\end{frame}

\begin{frame}
        BACKUP
\end{frame}

\begin{frame}
  \frametitle{Laser-Cut Case}
  \framesubtitle{Manufactured in plywood and acrylic at Ponoko}
  \vskip -0.2in
  \begin{columns}
  \column{0.5\textwidth}
    
  \column{0.5\textwidth}
     \\
    \vskip 0.2in
      \begin{itemize}
      \scriptsize
      \item Design all parts in LibreCAD
      \item Print each 1:1 and glue on foam core
      \item Fix mistakes on foam prototype
      \item \tgreen{It all fit first time!} \\
        \tblue{(total price US\$60 shipped, not bad)}
      \end{itemize}
  \end{columns}

\end{frame}

\begin{frame}
  \frametitle{Extras!}
  \framesubtitle{Simple ``assembler'' and program loader}
  \vskip -0.3in
  \tred{\scriptsize \tt \$./asm25.pl microstrip.txt} \\
  Source code entered by user ~~~~~~~ Listing with display codes \\
   \\
  \vskip 0.1in
  \scriptsize
  \tblue{Loader program (via USB):}\\
  \tred{\tt ~~~ \$./load\_prog /dev/ttyUSB0 microstrip.hex}
\end{frame}

\begin{frame}[fragile]
  \frametitle{Extras!}
  \framesubtitle{Emacs integration}

  \vskip -0.3in
  
  \vskip 0.2in

  \begin{columns}
  \column{0.4\textwidth}
    
    \vskip 0.2in
    
  \column{0.5\textwidth}
    \scriptsize
    \tblue{Cut/paste to/from Emacs buffer via USB interface} \\
    \tgreen{Example:  calculate PCB trace impedance}
      \begin{itemize}
      \scriptsize
      \item Perform calculation on Retro-25
      \item Press {\tt F1} key on keyboard in Emacs
      \item Type {\tt C-Y} to yank result to buffer
      \end{itemize}
    \vskip 0.3in
    Implemented as a C++ program ({\tt clip\_stack}) which can retrieve
    any stack level or storage register, plus a bit of Emacs lisp.
  \end{columns}
\end{frame}

\begin{frame}
  \frametitle{Final Tidbits}

  \tgreen{Speed}
  \begin{itemize}
  \scriptsize
  \item The original C version running on Z80 @ 4MHz was {\em really slow}! \\
  (maybe 25\% of HP-25 speed)
  \item I started to re-write the emulator in Z80 assembly \\
  {\em I would love to finish this someday, but...}
  \item Then I noticed that CMOS Z80 are available rated up to 20MHz
  \item I ended up running the Z80 at 16MHz, which results in an
  emulated speed within about 10\% of the original HP-25.  Not bad.
  \end{itemize}

  \vskip 0.2in
  
  \tviolet{What Next?}
  \scriptsize
  \begin{itemize}
  \item Finish Emacs integration
  \item Consider upgrade to HP-29C firmware
  \item Build a Nixie$^{TM}$ version?
  \end{itemize}

\end{frame}

\end{document}

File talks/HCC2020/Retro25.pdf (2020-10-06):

# The Retro-25 DIY Calculators


## E. Hazen

## October 4, 2020

Slide 1/14 | 2020-10-10 | E. Hazen

Personal and Professional History...

I’ve been fascinated by electronics since I was very young!


At age 13 (in 1973) I lived briefly in Leeds, England and worked at the Uni as an unpaid physics “graduate assistant”. I encountered an HP-9100 and taught myself to program it. I was immediately hooked!


In High School I made the acquaintance of an HP-2100 series computer running HP timeshare BASIC. We played various games (some legit, like TREK73) and others (posting the administrator password on the chalkboard) not so legit.


In 1975 my father bought an HP-25. I devoted myself to deliv-ering the Ann Arbor News faithfully to about 60 subscribers, and eventually I could afford my own HP-25 at $195.00 (about £663 today)


Unfortunately both HP-25 are now dead; mine fell in the fish tank with the piranhas while I was away and my roomies were scared to retrieve it! My father’s died when the batteries lost contact.

Slide 2/14 | 2020-10-10 | E. Hazen

# ...more history


I studied computer science for a while at Michigan and be-came expert with the model 29 keypunch (I hated that thing!) I did learn a few other things (ALGOL and S/370 assembly)


What really changed my life was working at Radio Shack. They introduced the TRS-80 and I immediately bought one (well, honestly, I put it on “lay-a-way” at my house!) I taught myself Z80 assembly language and wrote a simple multi-tasking kernel and FORTH system.


I parlayed my Z80 skills into a job at ETC (theatre lighting). I designed their IdeaTM and VisionTM lighting consoles, and wrote much of the low-level software in Z80 assembly (using my trusty TRS-80, now decked out with dual 8 inch floppies) as a dev system.


Since then I’ve worked at Boston University building electronics mostly for the LHC at CERN. I’ve also become somewhat of an HP collector, acquiring a 10C, 11C, 15C, 16C and 67. The 10C and 15C were filched, the 11C and 16C I use almost daily.

Slide 3/14 | 2020-10-10 | E. Hazen

# Why? Why? Why?

## Why a DIY HP-25?

I The HP-25 is my favorite calculator

I The display and keyboard are too small for middle-aged eyes
I I hate mouse- and touchscreen-based emulators (no tactile feel)
I I have a bunch of time on my hands (NOT!)


## Why use a Z80?

I I know them inside-out

I They were released about when the HP-25 came out

I I like designing and assembling good old thru-hole DIP boards

## Why the HECK VFD displays?

I Because they are cool!
(and nixies are a lot of trouble)
Slide 4/14 | 2020-10-10 | E. Hazen

# Specification

## Well, this is a hobby project so no spec needed, but I had goals:

## I Big, clicky buttons; display I can read without glasses

## I Simple hardware I could solder easily

## I Cross-development from my Linux machine

Slide 5/14 | 2020-10-10 | E. Hazen

# Parts! Parts! Parts!

I always start with the parts.

CPU: The Z80 is a no-brainer (initially Z80A, 4MHz)

Memory: first considered UV EPROM (nah!)


AT28C256-15 EEPROM and 62256LP-70 RAM (both 32k, DIP-28)

Display:
V1: 10mm red 10mm red common anode 7-segment
V2: IV-6 green vacuum fluorescent display tubes

Driver: ICM7218A MUX driver. I used these for theatre lighting consoles back in the day and they work well.

Switches: Cherry MX1A mechanical. These are my favorites!

Otherwise, I have drawers full of 74LS and 74S series TTL at work because we can’t bear to throw anything....

Slide 6/14 | 2020-10-10 | E. Hazen

# Boards!

How many boards? Started with a “toy” layout in ExpressPCB to see how everything fit. Looked like about 120x170mm. So, I fired up KiCAD and made a schematic and did a layout.


Slide 7/14 | 2020-10-10 | E. Hazen

# Schematics (KB, Display) GND

## d8 18 V⁺ ¹⁹


Almost no additional parts

# PCB (KB, Display)

Placement and routing pretty simple. Two header connectors, one for KB and one for LEDs

Top Cu area to GND
Bottom Cu area to VCC

Design rules based on what JLCPCB could do easily:
6 mil line/space (0.15 mm)
20 mil via with 10 mil hole
(0.5mm / 0.25mm)

Switches and LEDs take up most of front

Diodes and LED drivers on back


Slide 9/14 | 2020-10-10 | E. Hazen

# Schematics (CPU) C9

## uA7805 GND


to ROM access ROM WAIT STATES

2 wait states for EEPROM
(need for 20MHz CPU)

added to matrix at 45 and 55 CLOCK

May want 8, 20, 40 MHz options

# PCB (CPU)


Placement and routing pretty simple. Two header connectors, one for KB and one for LEDs
All components on the top.

Top and bottom Cu areas to GND

CPU, RAM, EEPROM in top row

Slide 11/14 | 2020-10-10 | E. Hazen

# Bringing it Up! (hardware)


## The boards and parts are here!

I Easy soldering (all thru-hole)
But then what? Software?
I Brief diversion to make a junk-box EEPROM programmer
I First program: delay, then HLT i.e. 2B 7C B5 20 FB 76
(glad I put a HALT LED on the board!)
I Then a struggle with bit-bang serial (next time use a UART!)
I Then write a debug monitor... “umon2”.
Two months later...
Slide 12/14 | 2020-10-10 | E. Hazen

# Bringing it Up! (software)

http://nonpareil.brouhaha.com


http://simpleavr.github.io/NP25/

https://github.com/z88dk/z88dk

https://www.autometer.de/
unix4fun/z80pack/ (https://www.autometer.de/unix4fun/z80pack/)

Download and study...

I Nonpareil by Eric Smith
Very complete, but quite complex as it supports many models
I NP25 “Nonpareil Physical” by Chris Chung Woodstock-only emulator for MSP430 Much more promising

In the end I took some of both, and got an HP-25 only simulation running in plain C under linux, using a tty for input and output.

Then, I built it using sdcc in Z88DK and tested it under the z80pack simulator.

Slide 13/14 | 2020-10-10 | E. Hazen

# Bringing it Up! (hardware+software)

Lots of loose ends...

First, write a serial boot loader

Then write a C program to send hex files


Then, work on the monitor...

d <addr> <count> | dump memory
e <addr> <dd> <dd>... | edit up to 16 bytes in memory
o <port> <val> | output <val> to <port>
z <val> | | set port zero value bits 0-6
i <port> | input from <port> and display
g <addr> | goto addr
b <addr> | set breakpoint (currently 3-byte call)
a <val1> <val2> | hex Arithmetic
c | | continue from breakpoint
c <addr> | continue, set new breakpoint
m <start> <end> <size> | memory region compare
p <start> <end> <size> | memory region copy
l | | binary load from serial
r | | repeat last command
k | | scan HP keyboard
f <addr> | dump HP registers from <addr> (A)
7 <addr> | update 7-segment display from <addr>
V <addr> | update VFD display from <addr>
I eventually needed all of those commands...

Finally, start to load and debug the calculator

Slide 14/14 | 2020-10-10 | E. Hazen

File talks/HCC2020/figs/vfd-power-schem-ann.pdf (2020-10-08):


VFD tubes need significant power:

1.2V @ 0.6A (filaments)
20.0V @ 0.6A (anodes)

18-25V Boost converter

2.5V buck converter

Shutdown circuits
(save tube life)
TTL control via Z80

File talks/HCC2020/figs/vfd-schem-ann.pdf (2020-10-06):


HV5812 driver
20 bit shift reg + HV

1.2V regulator
VFD filaments

Power: 5V, 2.5V, 20V

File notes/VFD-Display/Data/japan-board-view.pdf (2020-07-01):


Bottom View
from datasheet

Top view from board
(akafugu.jp)
1

2

11

3

8 9

10

View from this side

Pin circle diam ~ 8.6 mm
(0.340”)

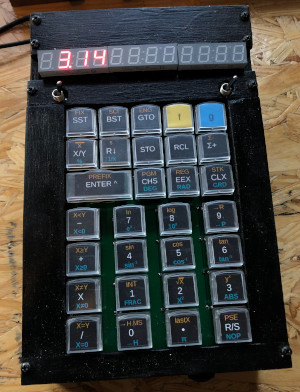
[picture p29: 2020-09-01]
talks/HCC2020/figs/led_front.jpg

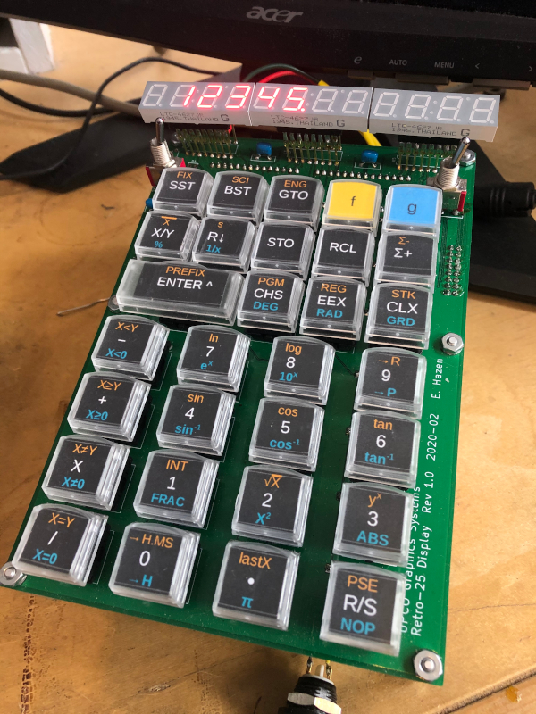
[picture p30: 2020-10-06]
talks/HCC2020/figs/front_view.jpg

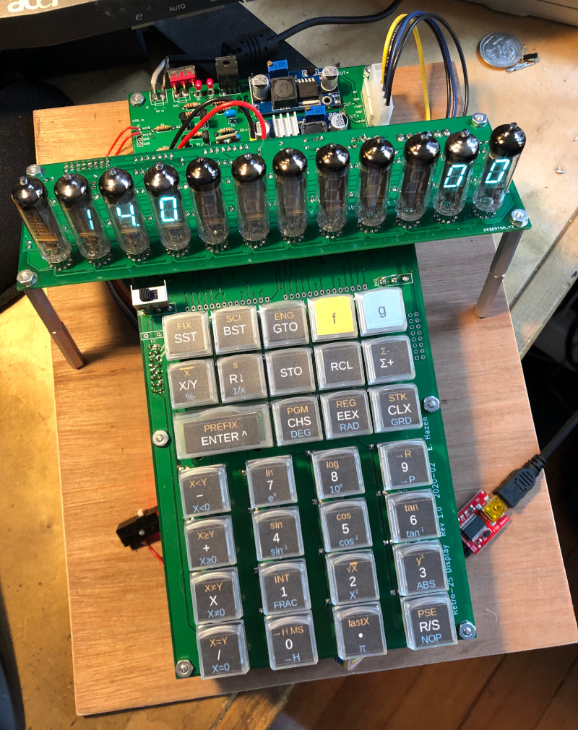
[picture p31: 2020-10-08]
photos/vfd-top-800.jpg

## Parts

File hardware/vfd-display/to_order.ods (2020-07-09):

Reference | Quantity | Value | Footprint | Datasheet | CatNo | Order
C1 C2 C5 C7 C9 C11 C12 | 7 | .01uF | Capacitor_THT:C_Disc_D3.8mm_W2.6mm_P2.50mm | ~ | 399-9824-ND | 10
C10 C4 | 2 | 10uF | Capacitor_THT:C_Disc_D3.8mm_W2.6mm_P2.50mm | ~ | 399-13950-ND | 3
C3 C6 | 2 | 1uF 50V | Capacitor_THT:C_Disc_D3.8mm_W2.6mm_P2.50mm | ~ | 399-14394-1-ND | 3
C8 | 1 | 10nF 50V | Capacitor_THT:C_Disc_D3.8mm_W2.6mm_P2.50mm | ~ | 399-9824-ND | 2
D1 D2 | 2 | LED | LED_THT:LED_D3.0mm | ~ | 1516-1344-ND | 3
J2 | 1 | Conn_01x06_Male | Connector_Molex:Molex_KK-396_A-41791-0006_1x06_P3.96mm_Vertical | ~ | WM4624-ND | 2
J3 | 1 | Conn_02x08_Odd_Even | Connector_PinHeader_2.54mm:PinHeader_2x08_P2.54mm_Vertical | ~ | 732-5299-ND | 2
U16 | 1 | LM1084-ADJ | Package_TO_SOT_THT:TO-220-3_Vertical | http://www.ti.com/lit/ds/symlink/lm1084.pdf | LM1084IT-ADJ/NOPB-ND | 2
U19 | 1 | 74LS125 | Package_DIP:DIP-14_W7.62mm_LongPads | http://www.ti.com/lit/gpn/sn74LS125 | 296-3664-5-ND | 2
U20 | 1 | 74LS174 | Package_DIP:DIP-16_W7.62mm_LongPads |  | 296-3664-5-ND | 2
U3 U11 U4 U12 U17 | 5 | HV5812 | Package_DIP:DIP-28_W15.24mm_LongPads | http://www.ti.com/lit/gpn/sn74LS125 | HV5812P-G-ND | 6
C1 | 1 | 10uF |  | 718-1212-ND | 718-1212-ND | 2
C2 | 1 | 0.33uF |  |  | 478-3188-ND | 2
RN1 | 1 | RPACK_SIP_8 | Resistor_THT:R_Array_SIP9 |  | 4609X-AP1-103LFCT-ND | 2
U1 U17 | 2 | 74AS74 |  |  | 296-1525-5-ND | 2
U2 | 1 | 74LS374 |  |  | 296-1662-5-ND | 2
U6 | 1 | 74HC14 |  |  | 296-1577-5-ND | 2

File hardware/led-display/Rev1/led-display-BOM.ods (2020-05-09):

Reference | Quantity | Value | Footprint | Datasheet
C1 C2 C3 | 3 | 0.1uF | Capacitor_THT:C_Disc_D9.0mm_W2.5mm_P5.00mm | ~
D1 | 1 | LED | LED_THT:LED_D2.0mm_W4.0mm_H2.8mm_FlatTop | ~
D10 D11 D12 D13 D14 D15 D16 D17 D18 D19 D2 D20 D21 D22 D23 D24 D25 D26 D27 D28 D29 D3 D30 D31 D4 D5 D6 D7 D8 D9 | 30 | 1N914 | Diode_THT:D_T-1_P2.54mm_Vertical_AnodeUp | ~
J1 J2 | 2 | C2x8100 | Connector_PinHeader_2.54mm:PinHeader_2x08_P2.54mm_Vertical | ~
R1 | 1 | 470 | Resistor_THT:R_Axial_DIN0207_L6.3mm_D2.5mm_P7.62mm_Horizontal | ~
SW1 SW2 | 2 | SW_SPST | Connector_PinHeader_2.54mm:PinHeader_1x03_P2.54mm_Vertical
SW10 SW11 SW12 SW13 SW14 SW15 SW16 SW17 SW18 SW19 SW20 SW21 SW22 SW23 SW24 SW25 SW26 SW27 SW28 SW29 SW3 SW30 SW31 SW32 SW4 SW6 SW7 SW8 SW9 | 29 | MX1A-C1NW | Button_Switch_Keyboard:SW_Cherry_MX1A_1.00u_PCB
SW5 | 1 | MX1A-C1NW | Button_Switch_Keyboard:SW_Cherry_MX1A_2.00u_PCB
U1 U4 | 2 | ICM7218A | Package_DIP:DIP-28_W15.24mm_LongPads | https://datasheets.maximintegrated.com/en/ds/ICM7218-ICM7228.pdf
U2 U3 U5 | 3 | LTC-4627JR | Package_DIP:DIP-16_W7.62mm_LongPads | http://www.kingbrightusa.com/images/catalog/SPEC/CA56-12EWA.pdf

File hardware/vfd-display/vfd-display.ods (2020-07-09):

Reference | Quantity | Value | Footprint | Datasheet | CatNo
C1 C2 C5 C7 C9 C11 C12 | 7 | .01uF | Capacitor_THT:C_Disc_D3.8mm_W2.6mm_P2.50mm | ~
C10 C4 | 2 | 10uF | Capacitor_THT:C_Disc_D3.8mm_W2.6mm_P2.50mm | ~ | 399-13950-ND
C3 C6 | 2 | 1uF 50V | Capacitor_THT:C_Disc_D3.8mm_W2.6mm_P2.50mm | ~ | 399-14394-1-ND
C8 | 1 | 10nF 50V | Capacitor_THT:C_Disc_D3.8mm_W2.6mm_P2.50mm | ~
D1 D2 | 2 | LED | LED_THT:LED_D3.0mm | ~ | 1516-1344-ND
J1 | 1 | conn_2x3 | Connector_PinHeader_2.54mm:PinHeader_2x03_P2.54mm_Vertical | ~
J2 | 1 | Conn_01x06_Male | Connector_Molex:Molex_KK-396_A-41791-0006_1x06_P3.96mm_Vertical | ~ | WM4624-ND
J3 | 1 | Conn_02x08_Odd_Even | Connector_PinHeader_2.54mm:PinHeader_2x08_P2.54mm_Vertical | ~ | 732-5299-ND
R1 | 1 | 100 | Resistor_THT:R_Axial_DIN0207_L6.3mm_D2.5mm_P10.16mm_Horizontal | ~
R2 | 1 | OMIT | Resistor_THT:R_Axial_DIN0207_L6.3mm_D2.5mm_P10.16mm_Horizontal | ~
R3 R5 R6 | 3 | 10k | Resistor_THT:R_Axial_DIN0207_L6.3mm_D2.5mm_P10.16mm_Horizontal | ~
R4 R7 | 2 | 470 | Resistor_THT:R_Axial_DIN0207_L6.3mm_D2.5mm_P10.16mm_Horizontal | ~
U1 U5 U9 U13 U7 U2 U6 U10 U14 U8 U15 U18 | 12 | IV-6 | iv-6:iv-6v2 | http://www.ti.com/lit/gpn/sn74LS125
U16 | 1 | LM1084-ADJ | Package_TO_SOT_THT:TO-220-3_Vertical | http://www.ti.com/lit/ds/symlink/lm1084.pdf | LM1084IT-ADJ/NOPB-ND
U19 | 1 | 74LS125 | Package_DIP:DIP-14_W7.62mm_LongPads | http://www.ti.com/lit/gpn/sn74LS125 | 296-3664-5-ND
U20 | 1 | 74LS174 | Package_DIP:DIP-16_W7.62mm_LongPads |  | 296-3664-5-ND
U3 U11 U4 U12 U17 | 5 | HV5812 | Package_DIP:DIP-28_W15.24mm_LongPads | http://www.ti.com/lit/gpn/sn74LS125 | HV5812P-G-ND

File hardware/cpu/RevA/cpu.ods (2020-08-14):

Reference | Quantity | Value | Footprint | Datasheet | CatNo | Order
C1 | 1 | 10uF |  | 718-1212-ND | 718-1212-ND | 2
C2 | 1 | 0.33uF |  |  | 478-3188-ND | 2
RN1 | 1 | RPACK_SIP_8 | Resistor_THT:R_Array_SIP9 |  | 4609X-AP1-103LFCT-ND | 2
U1 U17 | 2 | 74AS74 |  |  | 296-1525-5-ND | 2
U2 | 1 | 74LS374 |  |  | 296-1662-5-ND | 2
U6 | 1 | 74HC14 |  |  | 296-1577-5-ND | 2
C4 C6 C8 C10 C12 C14 C16 C18 C5 C7 C9 C11 C13 C15 C17 C19 C3 | 17 | 0.1uF |  |  | 478-3188-ND
D1 D3 | 2 | LED
D2 | 1 | 1N914 |  |  | 1N914ACT-ND
D5 D4 | 2 | 1N914 | Diode_THT:D_DO-35_SOD27_P7.62mm_Horizontal
J1 J3 | 2 | hdr_2x8
J2 | 1 | Conn_01x06
J5 | 1 | Conn_01x02 |  |  | A31676-ND
JP1 | 1 | jpr3
R1 R5 | 2 | 470
R2 R7 | 2 | 4.7k
R3 | 1 | 1k
R4 | 1 | 10k
SW1 | 1 | SW_Push |  |  | 401-1985-ND
U13 | 1 | 74LS32
U16 | 1 | uA7805 |  |  | MC7805CT-BPMS-ND
U3 | 1 | Z80CPU |  |  | Z84C0020PEG
U4 | 1 | AT28C256-15PU | Package_DIP:DIP-28_W15.24mm |  | AT28C256-15PU-ND
U5 | 1 | 74LS244
U7 | 1 | 74LS139
U8 | 1 | AS6C62256-55PCN | Package_DIP:DIP-28_W15.24mm |  | 1450-1033-ND
X1 | 1 | 20.000MHz | Oscillator:Oscillator_DIP-14 |  | 535-9220-5-ND,535-9209-5-ND,110-MXO45-3C-40M000000-ND

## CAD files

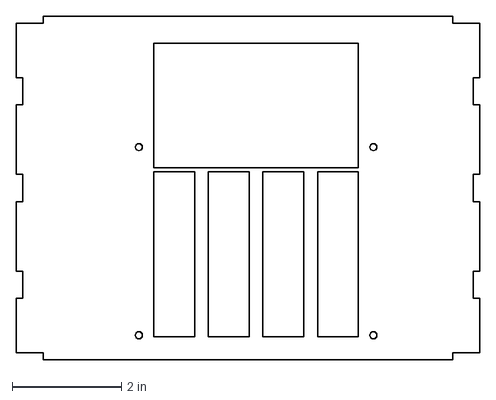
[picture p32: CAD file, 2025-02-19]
enclosure/vfd/laser/keyboard_plate3.dxf
8.50 x 6.30 in

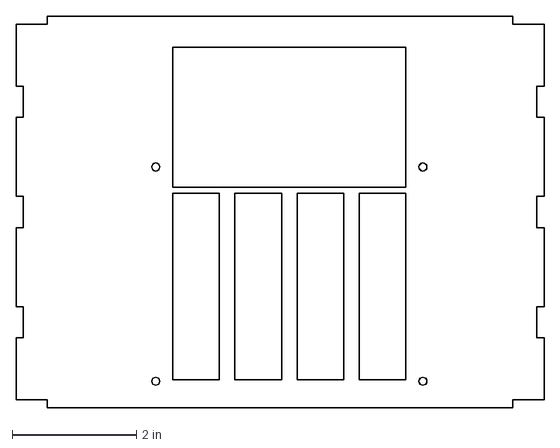
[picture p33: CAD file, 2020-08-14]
enclosure/vfd/laser/keyboard_plate2.dxf
8.50 x 6.30 in

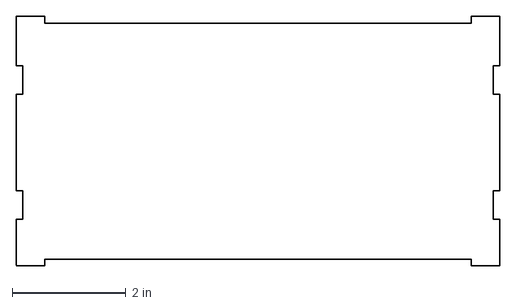
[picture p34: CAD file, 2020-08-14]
enclosure/vfd/laser/back.dxf
8.50 x 4.39 in

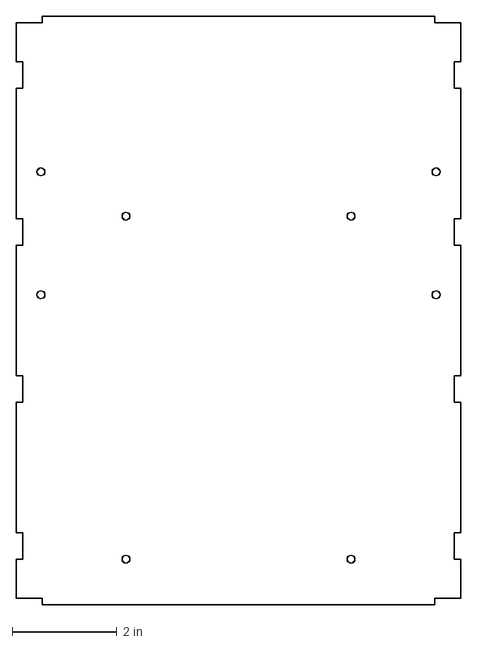
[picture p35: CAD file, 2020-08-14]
enclosure/vfd/laser/bottom_plate.dxf
8.50 x 11.2 in

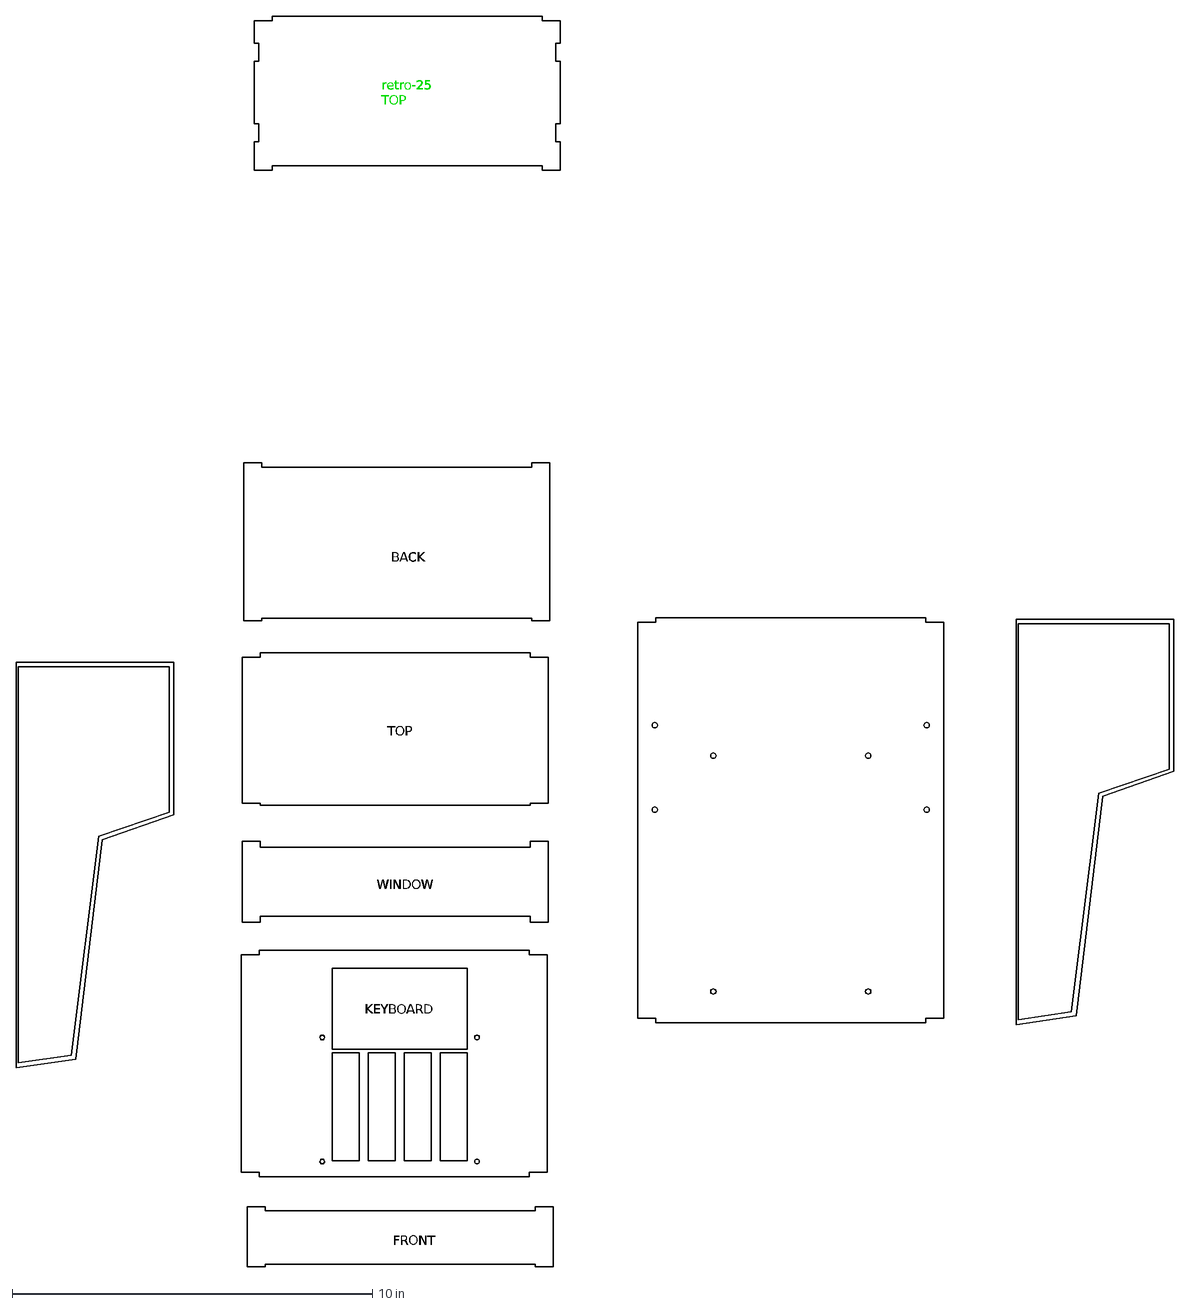
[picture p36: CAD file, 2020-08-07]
enclosure/vfd/all_parts.dxf
TOP
BACK
WINDOW
KEYBOARD
FRONT
retro-25 TOP

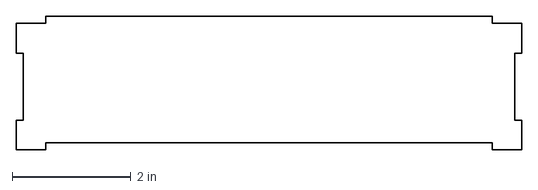
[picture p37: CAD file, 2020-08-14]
enclosure/vfd/laser/window.dxf
8.50 x 2.25 in

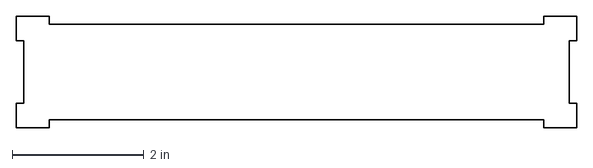
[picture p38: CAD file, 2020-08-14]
enclosure/vfd/laser/front.dxf
8.50 x 1.69 in

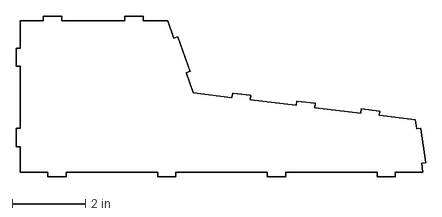
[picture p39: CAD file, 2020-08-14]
enclosure/vfd/laser/side.dxf
11.2 x 4.38 in

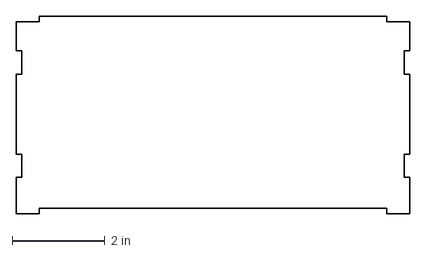
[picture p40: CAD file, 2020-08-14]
enclosure/vfd/laser/top.dxf
8.50 x 4.27 in

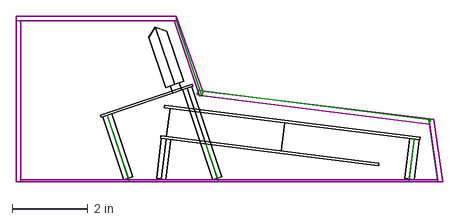
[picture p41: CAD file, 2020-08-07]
enclosure/vfd/side_view.dxf
11.3 x 4.38 in

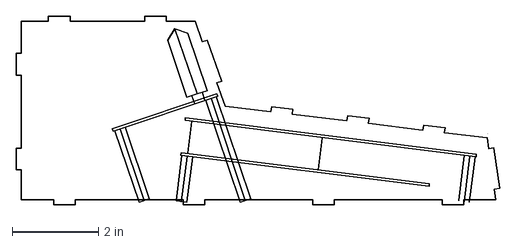
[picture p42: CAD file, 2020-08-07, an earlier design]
enclosure/vfd/side.dxf
11.2 x 4.38 in

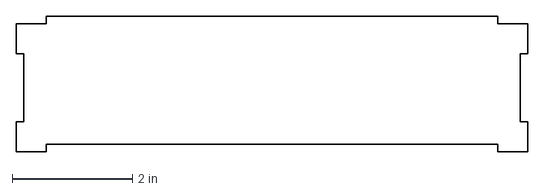
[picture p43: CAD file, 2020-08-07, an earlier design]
enclosure/vfd/window.dxf
8.50 x 2.25 in

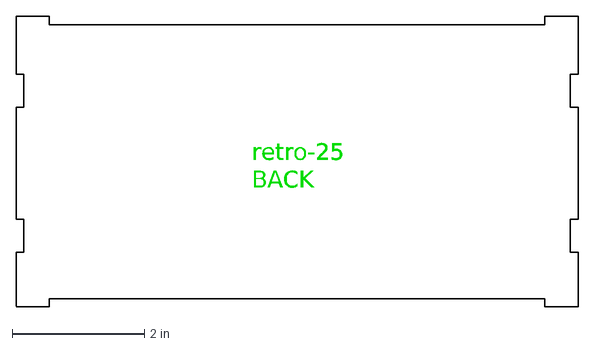
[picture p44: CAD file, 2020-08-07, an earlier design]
enclosure/vfd/back.dxf
retro-25 BACK

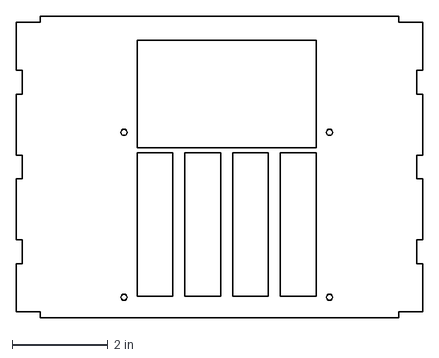
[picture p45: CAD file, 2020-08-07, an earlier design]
enclosure/vfd/keyboard_plate2.dxf
8.50 x 6.30 in

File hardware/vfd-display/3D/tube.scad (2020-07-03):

$fn = 100;
hgt = 35;
tit = 4;
dia = 13;
module tube() {
    union() {
        %cylinder(h=hgt,d=dia);
        translate( [0,0,hgt]) {
            %sphere(d=dia);
            translate( [0,0,dia/2-tit/2])
                %cylinder(h=tit,r1=1.5,r2=0.5);
        }   
//}
        for( i=[0:30:360]) {
            rotate( [0,0,i])
            translate([4,0,-10])
                color("black")
                cylinder(h=12,d=.4);
        }
    }
}

tube();

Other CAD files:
enclosure/vfd/front.dxf
enclosure/vfd/top.dxf
enclosure/vfd/bottom_plate.dxf

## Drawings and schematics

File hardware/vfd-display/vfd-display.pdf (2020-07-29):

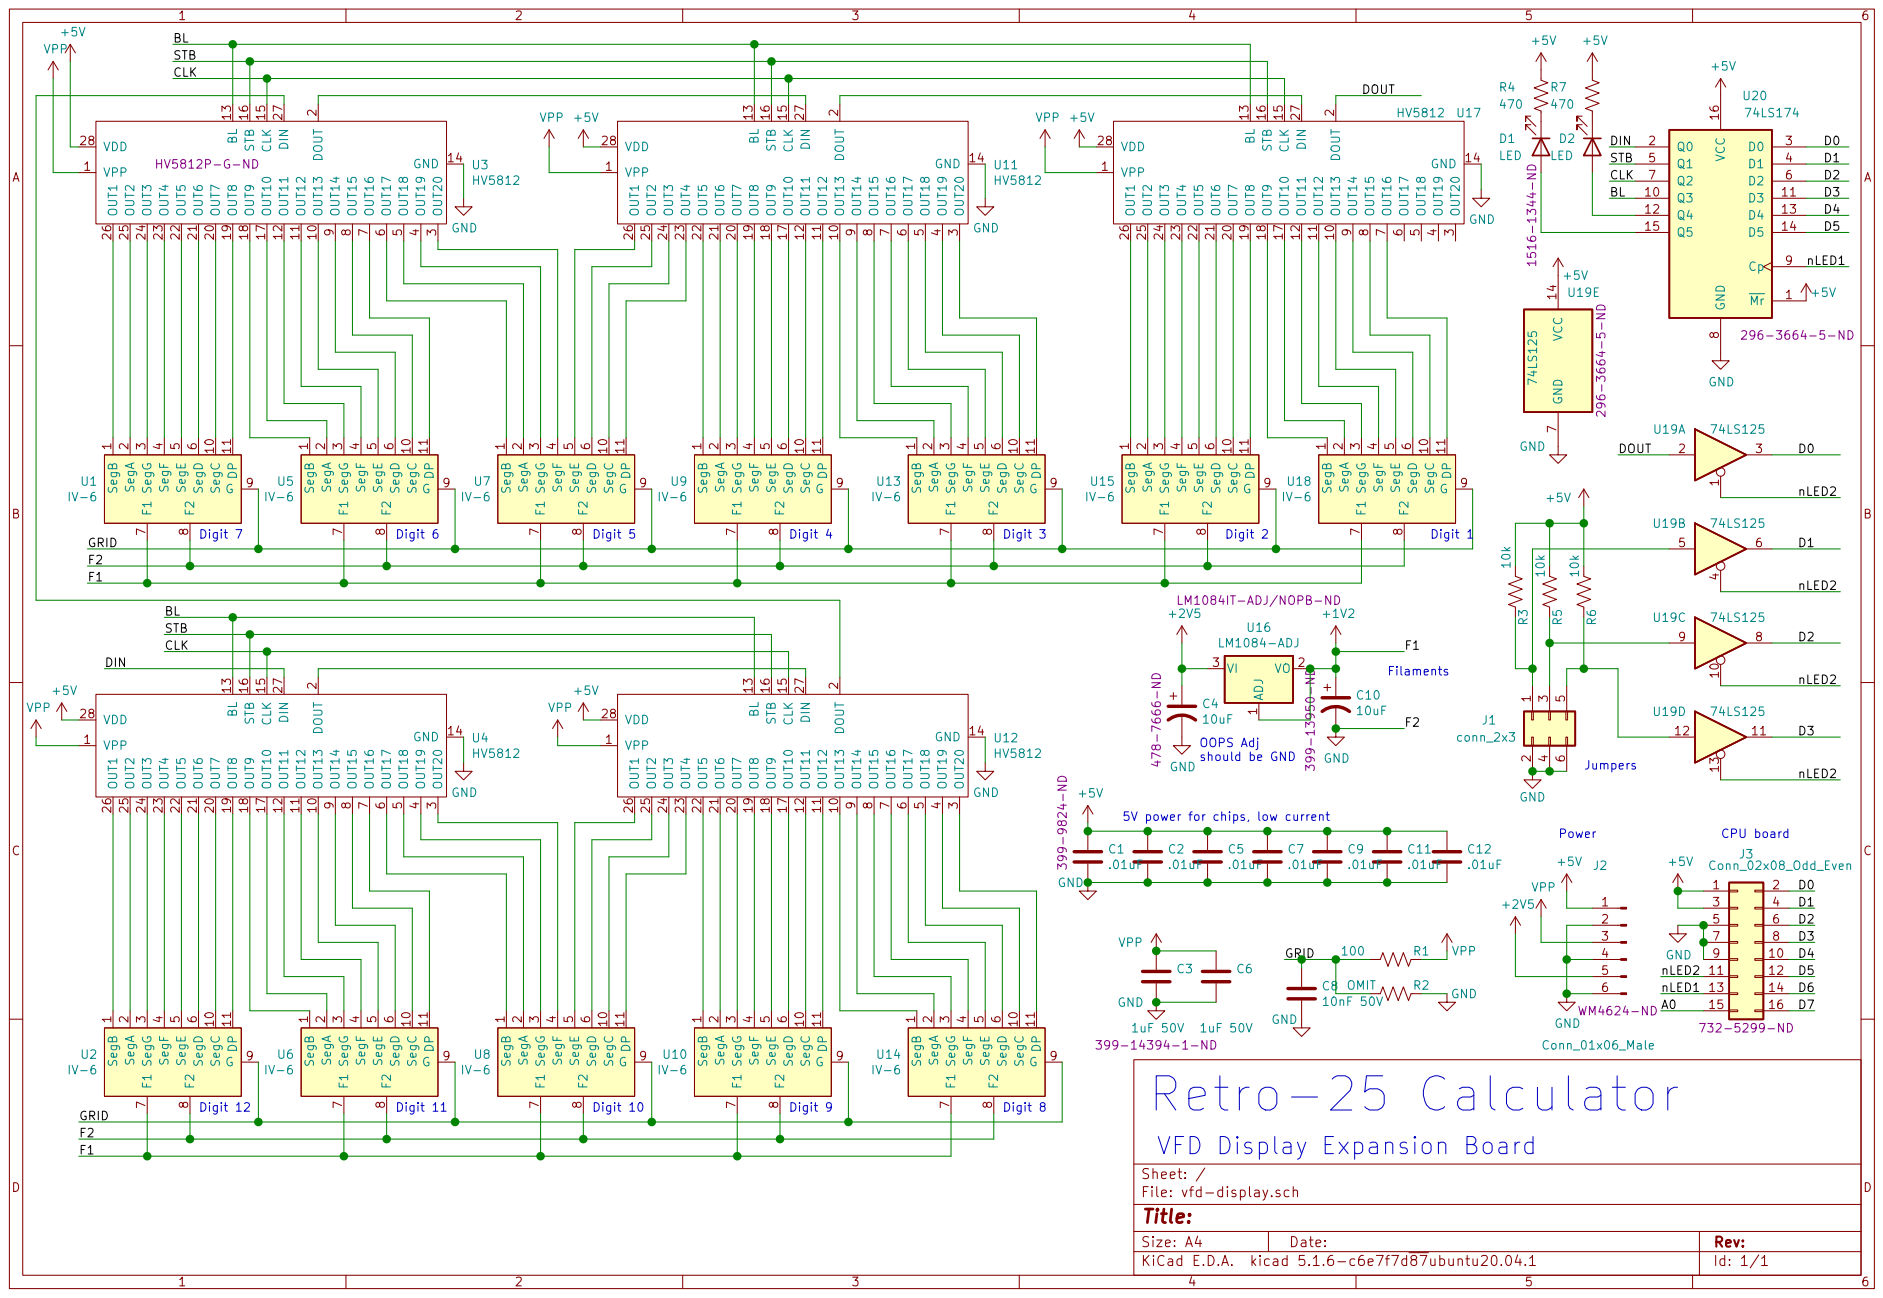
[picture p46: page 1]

2 SegG
LM1084-ADJ LM1084IT-ADJ/NOPB-ND SegB

Filaments 5V power for chips, low current

File: vfd-display.sch Sheet: / GND

VFD Display Expansion Board

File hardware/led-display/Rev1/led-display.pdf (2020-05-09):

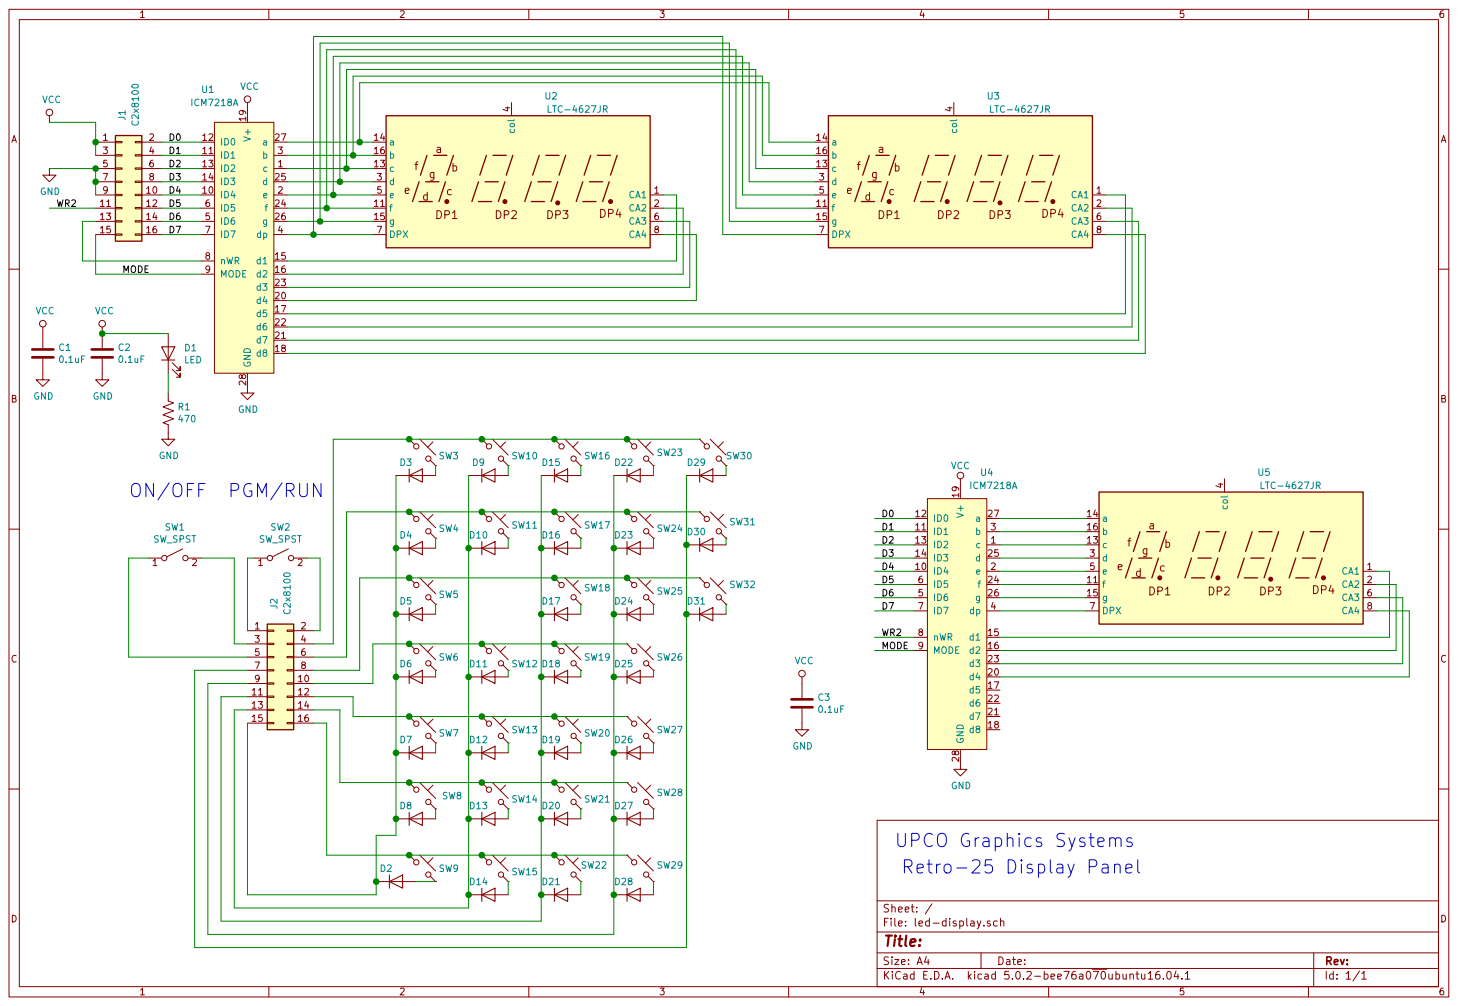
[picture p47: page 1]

11 | 12
13 | 14
15 | 16

File: led-display.sch Sheet: /
Id: 1/1 Title:

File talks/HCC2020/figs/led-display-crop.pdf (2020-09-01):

# d8 18 V⁺ ¹⁹ 27 GND 28

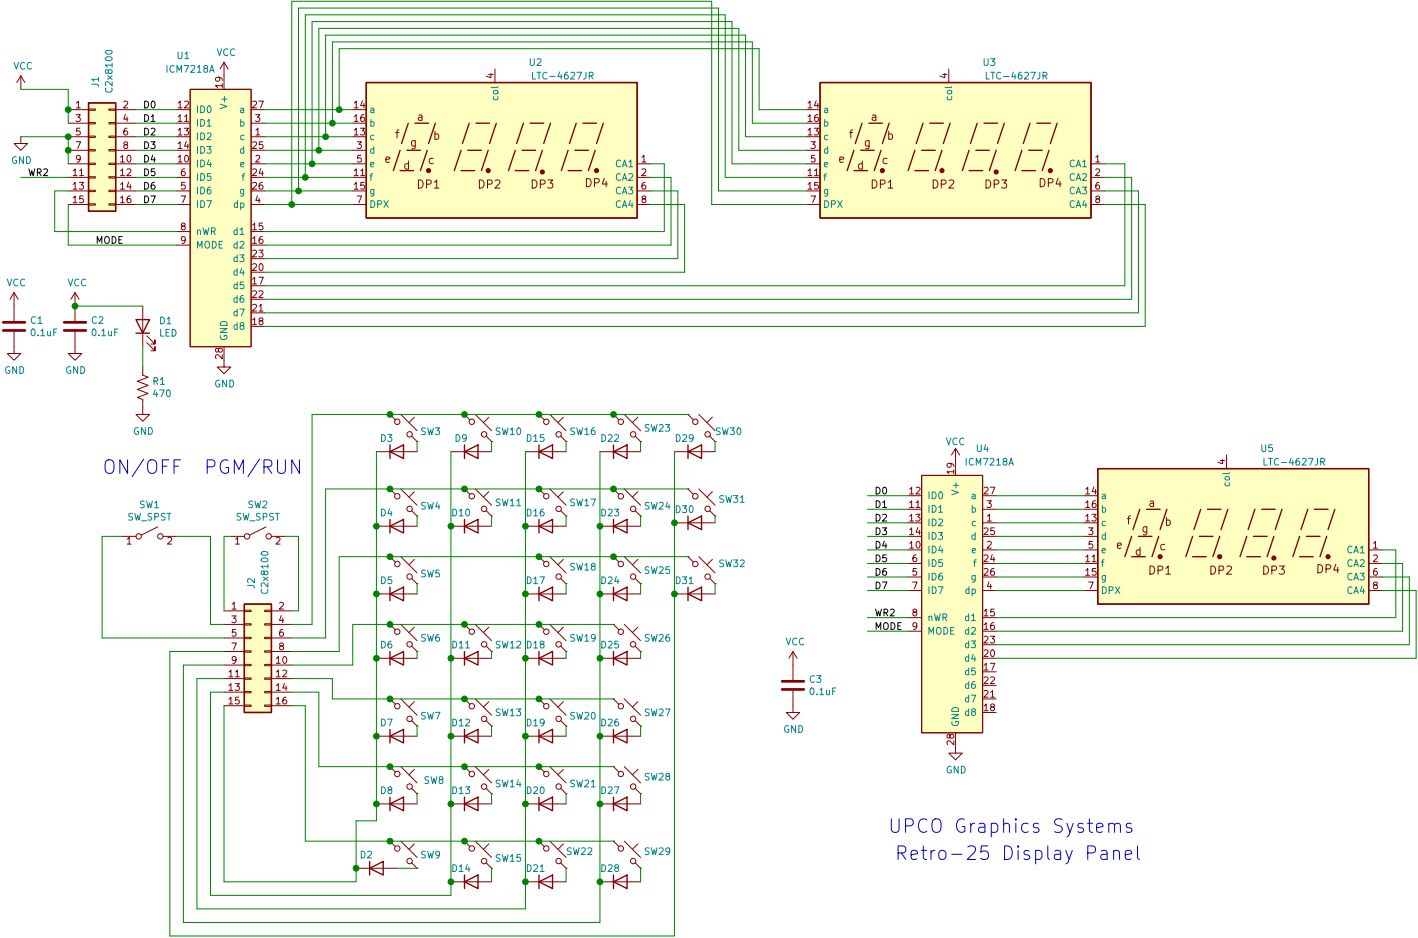
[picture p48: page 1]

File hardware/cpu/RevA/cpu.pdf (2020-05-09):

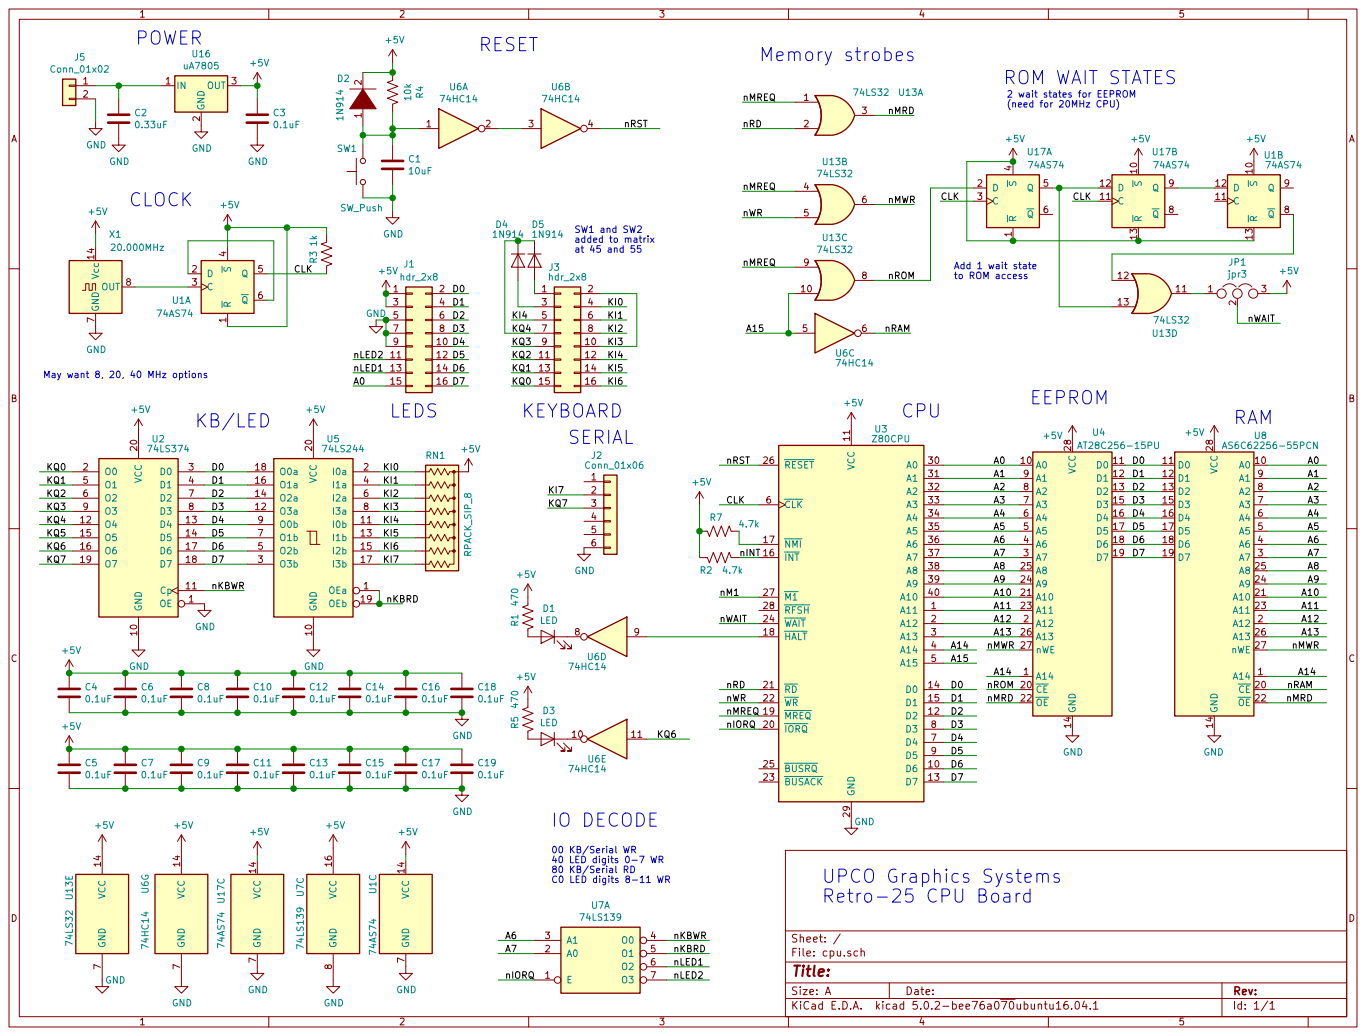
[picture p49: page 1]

nWAIT ROM WAIT STATES

2 wait states for EEPROM

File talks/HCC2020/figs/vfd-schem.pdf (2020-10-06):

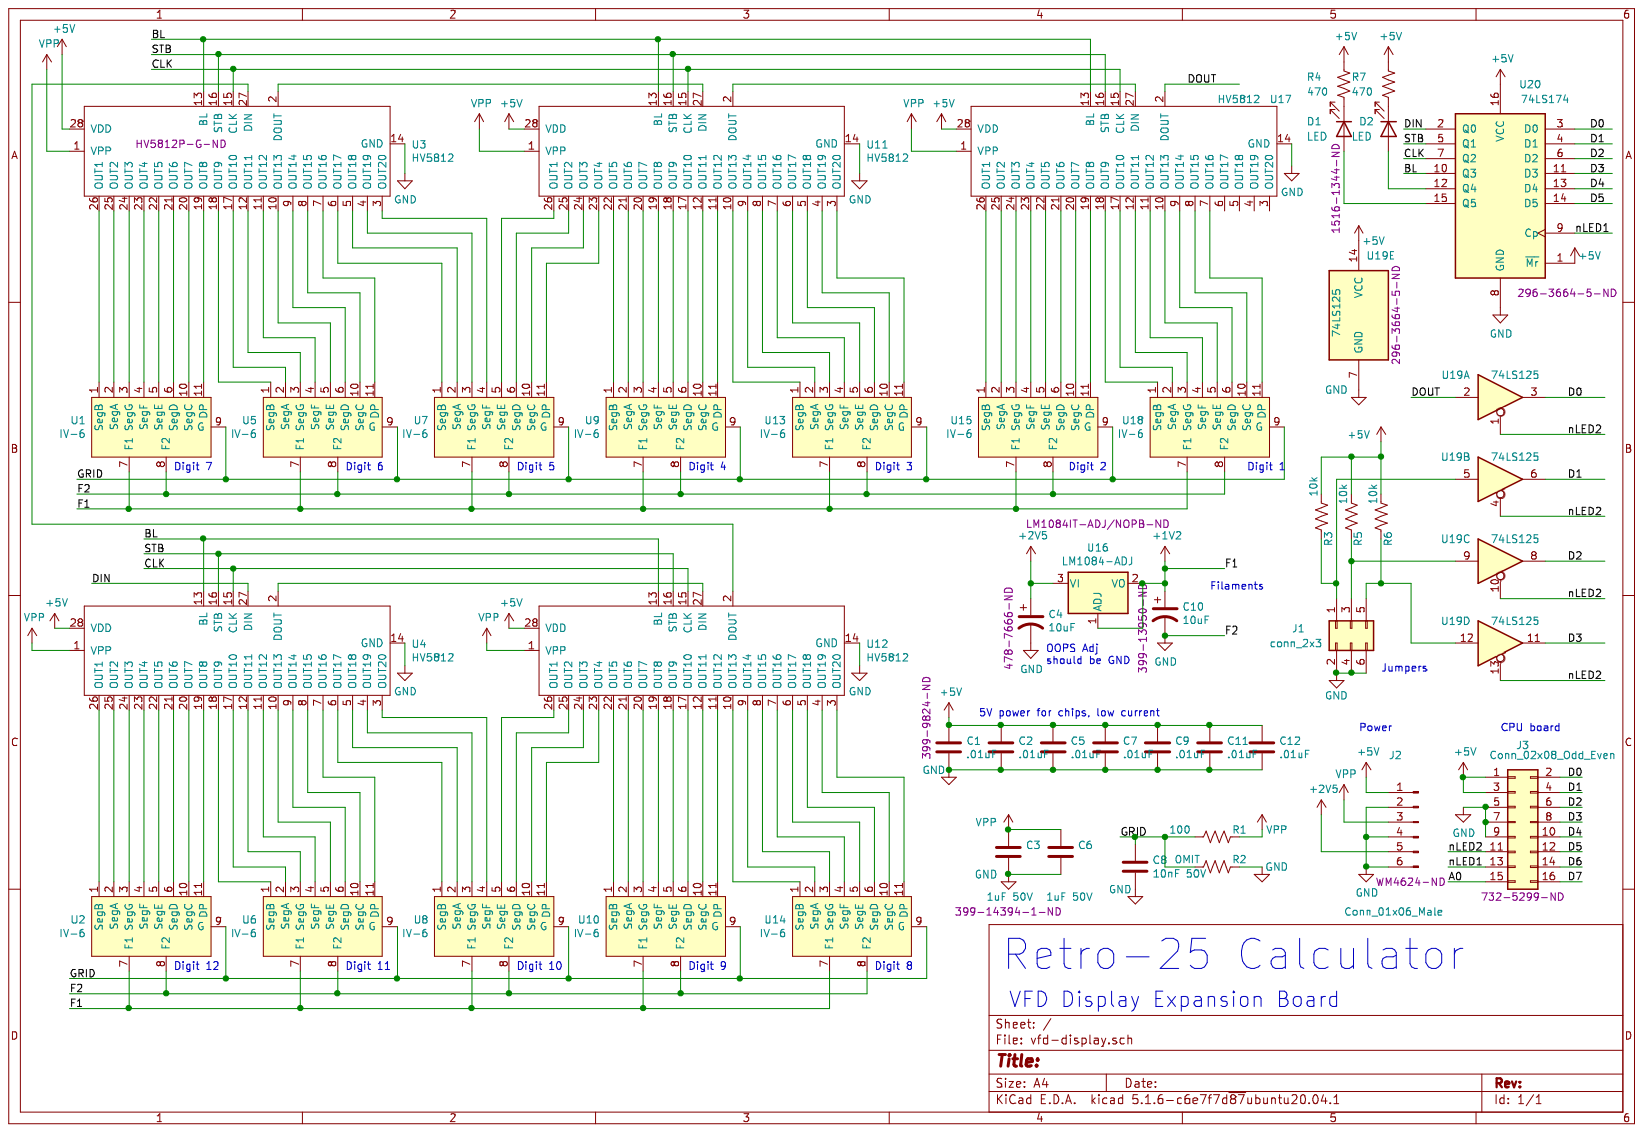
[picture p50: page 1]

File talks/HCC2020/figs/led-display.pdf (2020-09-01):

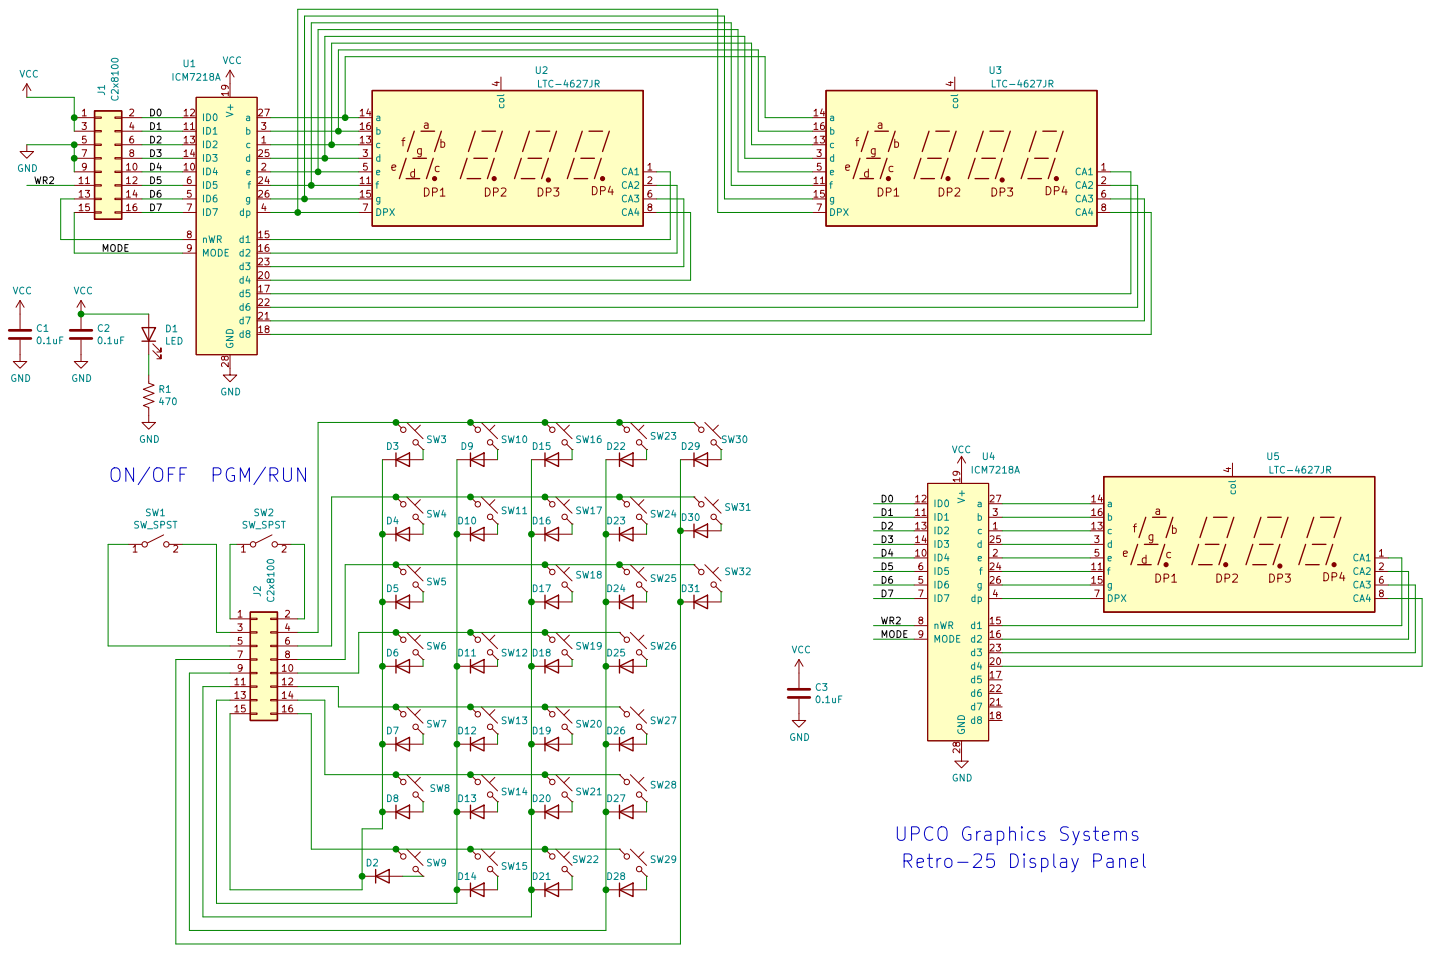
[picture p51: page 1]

11 | 12
13 | 14

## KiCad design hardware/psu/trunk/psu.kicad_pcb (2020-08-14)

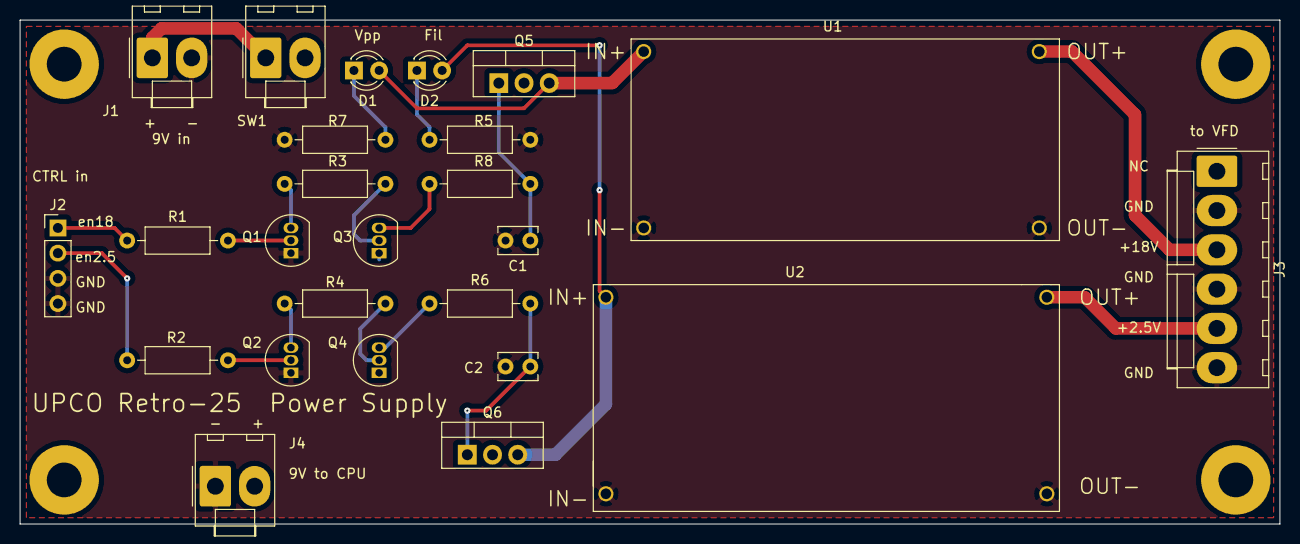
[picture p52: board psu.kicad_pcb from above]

Board: 2 copper layers, 127.0 x 50.8 mm, 25 parts (0 on the bottom side), 21 nets.

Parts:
C1, C2: 0.1uF; C_Disc_D3.8mm_W2.6mm_P2.50mm
D1, D2: LED; LED_D3.0mm
J1, J4: Conn_01x02_Male; Molex_KK-396_A-41791-0002_1x02_P3.96mm_Vertical
J2: Conn_01x04_Male; PinHeader_1x04_P2.54mm_Vertical
J3: Conn_01x06_Male; Molex_KK-396_A-41791-0006_1x06_P3.96mm_Vertical
Q1, Q2: 2N3904; TO-92_Inline
Q3, Q4: 2N3906; TO-92_Inline
Q5, Q6: IRF540N; TO-220-3_Vertical
R1, R2, R3, R4, R5, R6: R_US; R_Axial_DIN0207_L6.3mm_D2.5mm_P10.16mm_Horizontal
R7: 2.5k; R_Axial_DIN0207_L6.3mm_D2.5mm_P10.16mm_Horizontal
R8: 150; R_Axial_DIN0207_L6.3mm_D2.5mm_P10.16mm_Horizontal
SW1: SW_SPST; Molex_KK-396_A-41791-0002_1x02_P3.96mm_Vertical
U1: BOOST; ebay_XL6009
U2: BUCK; ebay_buck

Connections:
+9V: J4.2, Q3.1, Q4.1, Q5.2, Q6.2, SW1.2
GND: C1.2, C2.2, J1.2, J2.3, J2.4, J3.2, J3.4, J3.6, J4.1, Q1.1, Q2.1, R7.1, R8.1, U1.2, U1.4, U2.2, U2.4
unnamed: C1.1, Q5.1, R5.2
unnamed: C2.1, Q6.1, R6.2
unnamed: D1.1, R7.2
unnamed: D1.2, Q5.3, U1.1
unnamed: D2.1, R8.2
unnamed: D2.2, Q6.3, U2.1
unnamed: J1.1, SW1.1
unnamed: J2.1, R1.2
unnamed: J2.2, R2.2
unnamed: J3.3, U1.3
unnamed: J3.5, U2.3
unnamed: Q1.2, R1.1
unnamed: Q1.3, R3.2
unnamed: Q2.2, R2.1
unnamed: Q2.3, R4.2
unnamed: Q3.2, R3.1
unnamed: Q3.3, R5.1
unnamed: Q4.2, R4.1
unnamed: Q4.3, R6.1

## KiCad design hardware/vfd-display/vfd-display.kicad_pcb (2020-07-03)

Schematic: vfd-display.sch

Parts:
C1, C2, C5, C7, C9, C11, C12: .01uF; C_Disc_D3.8mm_W2.6mm_P2.50mm
C3, C6: 1uF 50V; C_Disc_D3.8mm_W2.6mm_P2.50mm
C4, C10: 10uF; C_Disc_D3.8mm_W2.6mm_P2.50mm
C8: 10nF 50V; C_Disc_D3.8mm_W2.6mm_P2.50mm
D1, D2: LED; LED_D3.0mm
J1: conn_2x3; PinHeader_2x03_P2.54mm_Vertical
J2: Conn_01x06_Male; Molex_KK-396_A-41791-0006_1x06_P3.96mm_Vertical
J3: Conn_02x08_Odd_Even; PinHeader_2x08_P2.54mm_Vertical
R1: 100; R_Axial_DIN0207_L6.3mm_D2.5mm_P10.16mm_Horizontal
R2: OMIT; R_Axial_DIN0207_L6.3mm_D2.5mm_P10.16mm_Horizontal
R3, R5, R6: 10k; R_Axial_DIN0207_L6.3mm_D2.5mm_P10.16mm_Horizontal
R4, R7: 470; R_Axial_DIN0207_L6.3mm_D2.5mm_P10.16mm_Horizontal
U1, U2, U5, U6, U7, U8, U9, U10, U13, U14, U15, U18: IV-6; iv-6v2
U3, U4, U11, U12, U17: HV5812; DIP-28_W15.24mm_LongPads
U16: LM1084-ADJ; TO-220-3_Vertical
U19: 74LS125; DIP-14_W7.62mm_LongPads
U20: 74LS174; DIP-16_W7.62mm_LongPads

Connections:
+1V2: C10.1, U1.7 (F1), U2.7 (F1), U5.7 (F1), U6.7 (F1), U7.7 (F1), U8.7 (F1), U9.7 (F1), U10.7 (F1), U13.7 (F1), U14.7 (F1), U15.7 (F1), U16.1, U16.2, U18.7 (F1)
+2V5: C4.1, J2.5, U16.3
+5V: C1.1, C2.1, C5.1, C7.1, C9.1, C11.1, C12.1, J2.1, J3.1, J3.3, R3.2, R4.1, R5.2, R6.2, R7.1, U3.28 (VDD), U4.28 (VDD), U11.28 (VDD), U12.28 (VDD), U17.28 (VDD), U19.14, U20.1, U20.16
/A0: J3.15
/BL: U3.13 (BL), U4.13 (BL), U11.13 (BL), U12.13 (BL), U17.13 (BL), U20.10
/CLK: U3.15 (CLK), U4.15 (CLK), U11.15 (CLK), U12.15 (CLK), U17.15 (CLK), U20.7
/D0: J3.2, U19.3, U20.3
/D1: J3.4, U19.6, U20.4
/D2: J3.6, U19.8, U20.6
/D3: J3.8, U19.11, U20.11
/D4: J3.10, U20.13
/D5: J3.12, U20.14
/D6: J3.14
/D7: J3.16
/DIN: U4.27 (DIN), U20.2
/DOUT: U17.2 (DOUT), U19.2
/GRID: C8.1, R1.2, R2.2, U1.9 (G), U2.9 (G), U5.9 (G), U6.9 (G), U7.9 (G), U8.9 (G), U9.9 (G), U10.9 (G), U13.9 (G), U14.9 (G), U15.9 (G), U18.9 (G)
/STB: U3.16 (STB), U4.16 (STB), U11.16 (STB), U12.16 (STB), U17.16 (STB), U20.5
/nLED1: J3.13, U20.9
/nLED2: J3.11, U19.1, U19.4, U19.10, U19.13
GND: C1.2, C2.2, C3.2, C4.2, C5.2, C6.2, C7.2, C8.2, C9.2, C10.2, C11.2, C12.2, J1.2, J1.4, J1.6, J2.2, J2.4, J2.6, J3.5, J3.7, J3.9, R2.1, U1.8 (F2), U2.8 (F2), U3.14 (GND), U4.14 (GND), U5.8 (F2), U6.8 (F2), U7.8 (F2), U8.8 (F2), U9.8 (F2), U10.8 (F2), U11.14 (GND), U12.14 (GND), U13.8 (F2), U14.8 (F2), U15.8 (F2), U17.14 (GND), U18.8 (F2), U19.7, U20.8
unnamed: D1.1, R4.2
unnamed: D1.2, U20.15
unnamed: D2.1, R7.2
unnamed: D2.2, U20.12
unnamed: J1.1, R3.1, U19.5
unnamed: J1.3, R5.1, U19.9
unnamed: J1.5, R6.1, U19.12
unnamed: U1.1 (SegB), U3.26 (OUT1)
unnamed: U1.2 (SegA), U3.25 (OUT2)
unnamed: U1.3 (SegG), U3.24 (OUT3)
unnamed: U1.4 (SegF), U3.23 (OUT4)
unnamed: U1.5 (SegE), U3.22 (OUT5)
unnamed: U1.6 (SegD), U3.21 (OUT6)
unnamed: U1.10 (SegC), U3.20 (OUT7)
unnamed: U1.11 (DP), U3.19 (OUT8)
unnamed: U2.1 (SegB), U4.26 (OUT1)
unnamed: U2.2 (SegA), U4.25 (OUT2)
unnamed: U2.3 (SegG), U4.24 (OUT3)
unnamed: U2.4 (SegF), U4.23 (OUT4)
unnamed: U2.5 (SegE), U4.22 (OUT5)
unnamed: U2.6 (SegD), U4.21 (OUT6)
unnamed: U2.10 (SegC), U4.20 (OUT7)
unnamed: U2.11 (DP), U4.19 (OUT8)
unnamed: U3.3 (OUT20), U7.4 (SegF)
unnamed: U3.4 (OUT19), U7.3 (SegG)
unnamed: U3.5 (OUT18), U7.2 (SegA)
unnamed: U3.6 (OUT17), U7.1 (SegB)
unnamed: U3.7 (OUT16), U5.11 (DP)
unnamed: U3.8 (OUT15), U5.10 (SegC)
unnamed: U3.9 (OUT14), U5.6 (SegD)
unnamed: U3.10 (OUT13), U5.5 (SegE)
unnamed: U3.11 (OUT12), U5.4 (SegF)
unnamed: U3.12 (OUT11), U5.3 (SegG)
unnamed: U3.17 (OUT10), U5.2 (SegA)
unnamed: U3.18 (OUT9), U5.1 (SegB)
unnamed: U4.3 (OUT20), U8.4 (SegF)
unnamed: U4.4 (OUT19), U8.3 (SegG)
unnamed: U4.5 (OUT18), U8.2 (SegA)
unnamed: U4.6 (OUT17), U8.1 (SegB)
unnamed: U4.7 (OUT16), U6.11 (DP)
unnamed: U4.8 (OUT15), U6.10 (SegC)
unnamed: U4.9 (OUT14), U6.6 (SegD)
unnamed: U4.10 (OUT13), U6.5 (SegE)
unnamed: U4.11 (OUT12), U6.4 (SegF)
unnamed: U4.12 (OUT11), U6.3 (SegG)
unnamed: U4.17 (OUT10), U6.2 (SegA)
unnamed: U4.18 (OUT9), U6.1 (SegB)
unnamed: U10.1 (SegB), U12.22 (OUT5)
unnamed: U10.2 (SegA), U12.21 (OUT6)
unnamed: U10.3 (SegG), U12.20 (OUT7)
unnamed: U10.4 (SegF), U12.19 (OUT8)
unnamed: U10.5 (SegE), U12.18 (OUT9)
unnamed: U10.6 (SegD), U12.17 (OUT10)
unnamed: U10.10 (SegC), U12.12 (OUT11)
unnamed: U10.11 (DP), U12.11 (OUT12)
unnamed: U11.2 (DOUT), U17.27 (DIN)
unnamed: U11.3 (OUT20), U13.11 (DP)
unnamed: U11.4 (OUT19), U13.10 (SegC)
unnamed: U11.5 (OUT18), U13.6 (SegD)
unnamed: U11.6 (OUT17), U13.5 (SegE)
unnamed: U11.7 (OUT16), U13.4 (SegF)
unnamed: U11.8 (OUT15), U13.3 (SegG)
unnamed: U11.9 (OUT14), U13.2 (SegA)
unnamed: U11.10 (OUT13), U13.1 (SegB)
unnamed: U9.11 (DP), U11.11 (OUT12)
unnamed: U9.10 (SegC), U11.12 (OUT11)
unnamed: U9.6 (SegD), U11.17 (OUT10)
unnamed: U9.5 (SegE), U11.18 (OUT9)
unnamed: U9.4 (SegF), U11.19 (OUT8)
unnamed: U9.3 (SegG), U11.20 (OUT7)
unnamed: U9.2 (SegA), U11.21 (OUT6)
unnamed: U9.1 (SegB), U11.22 (OUT5)
unnamed: U7.11 (DP), U11.23 (OUT4)
unnamed: U7.10 (SegC), U11.24 (OUT3)
unnamed: U7.6 (SegD), U11.25 (OUT2)
unnamed: U7.5 (SegE), U11.26 (OUT1)
unnamed: U3.2 (DOUT), U11.27 (DIN)
unnamed: U3.27 (DIN), U12.2 (DOUT)
unnamed: U12.3 (OUT20), U14.11 (DP)
unnamed: U12.4 (OUT19), U14.10 (SegC)
unnamed: U12.5 (OUT18), U14.6 (SegD)
unnamed: U12.6 (OUT17), U14.5 (SegE)
unnamed: U12.7 (OUT16), U14.4 (SegF)
unnamed: U12.8 (OUT15), U14.3 (SegG)
unnamed: U12.9 (OUT14), U14.2 (SegA)
unnamed: U12.10 (OUT13), U14.1 (SegB)
unnamed: U8.11 (DP), U12.23 (OUT4)
unnamed: U8.10 (SegC), U12.24 (OUT3)
unnamed: U8.6 (SegD), U12.25 (OUT2)
unnamed: U8.5 (SegE), U12.26 (OUT1)
unnamed: U4.2 (DOUT), U12.27 (DIN)
unnamed: U15.1 (SegB), U17.26 (OUT1)
unnamed: U15.2 (SegA), U17.25 (OUT2)
unnamed: U15.3 (SegG), U17.24 (OUT3)
unnamed: U15.4 (SegF), U17.23 (OUT4)
unnamed: U15.5 (SegE), U17.22 (OUT5)
unnamed: U15.6 (SegD), U17.21 (OUT6)
unnamed: U15.10 (SegC), U17.20 (OUT7)
unnamed: U15.11 (DP), U17.19 (OUT8)
unnamed: U17.7 (OUT16), U18.11 (DP)
unnamed: U17.8 (OUT15), U18.10 (SegC)
unnamed: U17.9 (OUT14), U18.6 (SegD)
unnamed: U17.10 (OUT13), U18.5 (SegE)
unnamed: U17.11 (OUT12), U18.4 (SegF)
unnamed: U17.12 (OUT11), U18.3 (SegG)
unnamed: U17.17 (OUT10), U18.2 (SegA)
unnamed: U17.18 (OUT9), U18.1 (SegB)
VPP: C3.1, C6.1, J2.3, R1.1, U3.1 (VPP), U4.1 (VPP), U11.1 (VPP), U12.1 (VPP), U17.1 (VPP)

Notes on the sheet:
5V power for chips, low current
Filaments
CPU board
Power
Jumpers
Retro-25 Calculator
VFD Display Expansion Board

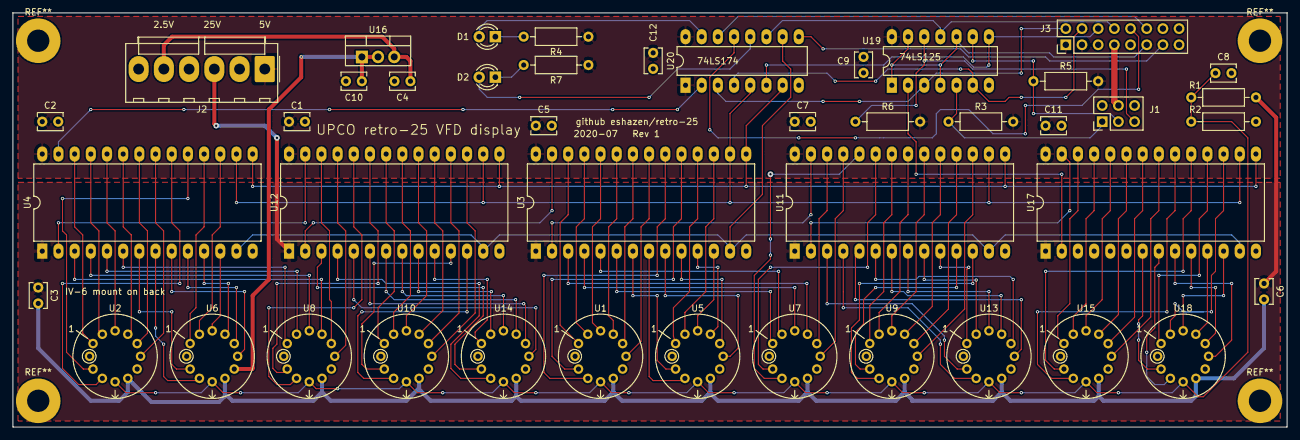
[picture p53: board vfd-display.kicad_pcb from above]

Board: 2 copper layers, 200.0 x 65.0 mm, 44 parts (0 on the bottom side), 126 nets.

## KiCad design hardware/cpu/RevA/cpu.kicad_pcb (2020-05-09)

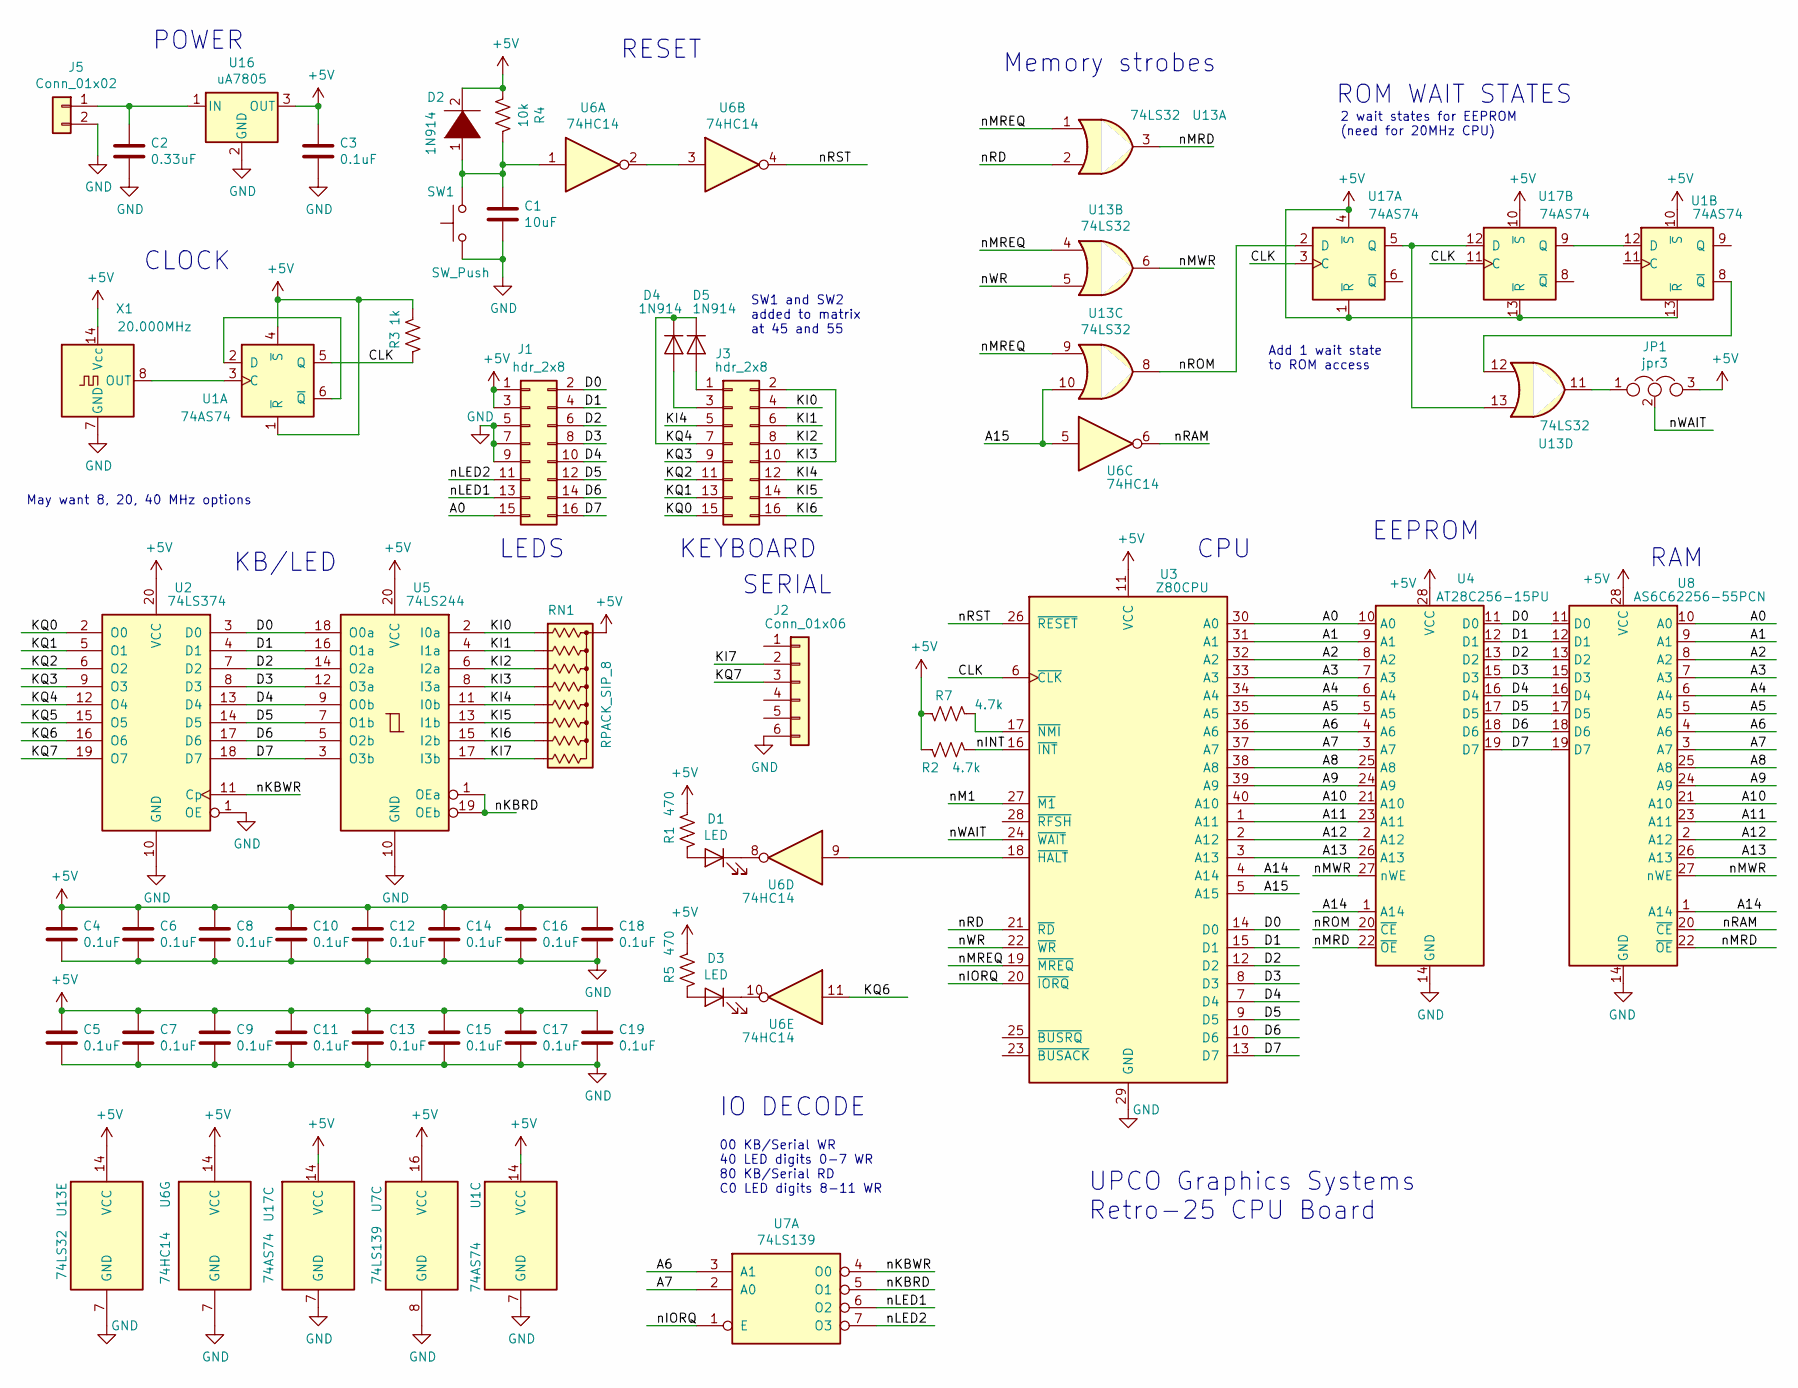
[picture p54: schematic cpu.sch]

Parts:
C1: 10uF
C2: 0.33uF
C3, C4, C5, C6, C7, C8, C9, C10, C11, C12, C13, C14, C15, C16, C17, C18, C19: 0.1uF
D1, D3: LED
D2: 1N914
D4, D5: 1N914; D_DO-35_SOD27_P7.62mm_Horizontal
J1, J3: hdr_2x8
J2: Conn_01x06
J5: Conn_01x02
JP1: jpr3
R1, R5: 470
R2, R7: 4.7k
R3: 1k
R4: 10k
RN1: RPACK_SIP_8; R_Array_SIP9
SW1: SW_Push
U1, U17: 74AS74
U2: 74LS374
U3: Z80CPU
U4: AT28C256-15PU; DIP-28_W15.24mm
U5: 74LS244
U6: 74HC14
U7: 74LS139
U8: AS6C62256-55PCN; DIP-28_W15.24mm
U13: 74LS32
U16: uA7805
X1: 20.000MHz; Oscillator_DIP-14

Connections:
+5V: C3.1, C4.1, C5.1, C6.1, C7.1, C8.1, C9.1, C10.1, C11.1, C12.1, C13.1, C14.1, C15.1, C16.1, C17.1, C18.1, C19.1, D2.2 (A), J1.1, J1.3, JP1.3, R1.2, R2.2, R3.2, R4.2, R5.2, R7.2, RN1.1 (common), U1.1 (~R), U1.4 (~S), U1.10 (~S), U1.13 (~R), U1.14 (VCC), U2.20 (VCC), U3.11 (VCC), U4.28 (VCC), U5.20 (VCC), U6.14 (VCC), U7.16 (VCC), U8.28 (VCC), U13.14 (VCC), U16.3 (OUT), U17.1 (~R), U17.4 (~S), U17.10 (~S), U17.13 (~R), U17.14 (VCC), X1.14 (Vcc)
/A0: J1.15, U3.30 (A0), U4.10 (A0), U8.10 (A0)
/A1: U3.31 (A1), U4.9 (A1), U8.9 (A1)
/A2: U3.32 (A2), U4.8 (A2), U8.8 (A2)
/A3: U3.33 (A3), U4.7 (A3), U8.7 (A3)
/A4: U3.34 (A4), U4.6 (A4), U8.6 (A4)
/A5: U3.35 (A5), U4.5 (A5), U8.5 (A5)
/A6: U3.36 (A6), U4.4 (A6), U7.3 (A1), U8.4 (A6)
/A7: U3.37 (A7), U4.3 (A7), U7.2 (A0), U8.3 (A7)
/A8: U3.38 (A8), U4.25 (A8), U8.25 (A8)
/A9: U3.39 (A9), U4.24 (A9), U8.24 (A9)
/A10: U3.40 (A10), U4.21 (A10), U8.21 (A10)
/A11: U3.1 (A11), U4.23 (A11), U8.23 (A11)
/A12: U3.2 (A12), U4.2 (A12), U8.2 (A12)
/A13: U3.3 (A13), U4.26 (A13), U8.26 (A13)
/A14: U3.4 (A14), U4.1 (A14), U8.1 (A14)
/A15: U3.5 (A15), U6.5, U13.10
/CLK: R3.1, U1.5 (Q), U3.6 (~CLK~), U17.3 (C), U17.11 (C)
/D0: J1.2, U2.3 (D0), U3.14 (D0), U4.11 (D0), U5.18 (O0a), U8.11 (D0)
/D1: J1.4, U2.4 (D1), U3.15 (D1), U4.12 (D1), U5.16 (O1a), U8.12 (D1)
/D2: J1.6, U2.7 (D2), U3.12 (D2), U4.13 (D2), U5.14 (O2a), U8.13 (D2)
/D3: J1.8, U2.8 (D3), U3.8 (D3), U4.15 (D3), U5.12 (O3a), U8.15 (D3)
/D4: J1.10, U2.13 (D4), U3.7 (D4), U4.16 (D4), U5.9 (O0b), U8.16 (D4)
/D5: J1.12, U2.14 (D5), U3.9 (D5), U4.17 (D5), U5.7 (O1b), U8.17 (D5)
/D6: J1.14, U2.17 (D6), U3.10 (D6), U4.18 (D6), U5.5 (O2b), U8.18 (D6)
/D7: J1.16, U2.18 (D7), U3.13 (D7), U4.19 (D7), U5.3 (O3b), U8.19 (D7)
/KI0: J3.4, RN1.2 (R1), U5.2 (I0a)
/KI1: J3.6, RN1.3 (R2), U5.4 (I1a)
/KI2: J3.8, RN1.4 (R3), U5.6 (I2a)
/KI3: J3.2, J3.10, RN1.5 (R4), U5.8 (I3a)
/KI4: J3.5, J3.12, RN1.6 (R5), U5.11 (I0b)
/KI5: J3.14, RN1.7 (R6), U5.13 (I1b)
/KI6: J3.16, RN1.8 (R7), U5.15 (I2b)
/KI7: J2.2, RN1.9 (R8), U5.17 (I3b)
/KQ0: J3.15, U2.2 (O0)
/KQ1: J3.13, U2.5 (O1)
/KQ2: J3.11, U2.6 (O2)
/KQ3: J3.9, U2.9 (O3)
/KQ4: D4.1 (K), D5.1 (K), J3.7, U2.12 (O4)
/KQ5: U2.15 (O5)
/KQ6: U2.16 (O6), U6.11
/KQ7: J2.3, U2.19 (O7)
/nINT: R2.1, U3.16 (~INT~)
/nIORQ: U3.20 (~IORQ~), U7.1 (E)
/nKBRD: U5.1 (OEa), U5.19 (OEb), U7.5 (O1)
/nKBWR: U2.11 (Cp), U7.4 (O0)
/nLED1: J1.13, U7.6 (O2)
/nLED2: J1.11, U7.7 (O3)
/nM1: U3.27 (~M1~)
/nMRD: U4.22 (~OE), U8.22 (~OE), U13.3
/nMREQ: U3.19 (~MREQ~), U13.1, U13.4, U13.9
/nMWR: U4.27 (nWE), U8.27 (nWE), U13.6
/nRAM: U6.6, U8.20 (~CE)
/nRD: U3.21 (~RD~), U13.2
/nROM: U4.20 (~CE), U13.8, U17.2 (D)
/nRST: U3.26 (~RESET~), U6.4
/nWAIT: JP1.2, U3.24 (~WAIT~)
/nWR: U3.22 (~WR~), U13.5
GND: C1.2, C2.2, C3.2, C4.2, C5.2, C6.2, C7.2, C8.2, C9.2, C10.2, C11.2, C12.2, C13.2, C14.2, C15.2, C16.2, C17.2, C18.2, C19.2, J1.5, J1.7, J1.9, J2.6, J5.2, SW1.2, U1.7 (GND), U2.1 (OE), U2.10 (GND), U3.29 (GND), U4.14 (GND), U5.10 (GND), U6.7 (GND), U7.8 (GND), U8.14 (GND), U13.7 (GND), U16.2 (GND), U17.7 (GND), X1.7 (GND)
unnamed: C1.1, D2.1 (K), R4.1, SW1.1, U6.1
unnamed: C2.1, J5.1, U16.1 (IN)
unnamed: D1.1 (K), U6.8
unnamed: D1.2 (A), R1.1
unnamed: D3.1 (K), U6.10
unnamed: D3.2 (A), R5.1
unnamed: D4.2 (A), J3.3
unnamed: D5.2 (A), J3.1
unnamed: JP1.1, U13.11
unnamed: R7.1, U3.17 (~NMI~)
unnamed: U1.2 (D), U1.6 (~Q)
unnamed: U1.3 (C), X1.8 (OUT)
unnamed: U1.8 (~Q), U13.12
unnamed: U1.12 (D), U17.9 (Q)
unnamed: U3.18 (~HALT~), U6.9
unnamed: U6.2, U6.3
unnamed: U13.13, U17.5 (Q), U17.12 (D)

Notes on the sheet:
KB/LED
CLOCK
RESET
CPU
EEPROM
RAM
Memory strobes
ROM WAIT STATES
Add 1 wait state to ROM access
IO DECODE
00 KB/Serial WR 40 LED digits 0-7 WR 80 KB/Serial RD C0 LED digits 8-11 WR
SW1 and SW2 added to matrix at 45 and 55
LEDS
KEYBOARD
SERIAL
POWER
UPCO Graphics Systems Retro-25 CPU Board
2 wait states for EEPROM (need for 20MHz CPU)
May want 8, 20, 40 MHz options

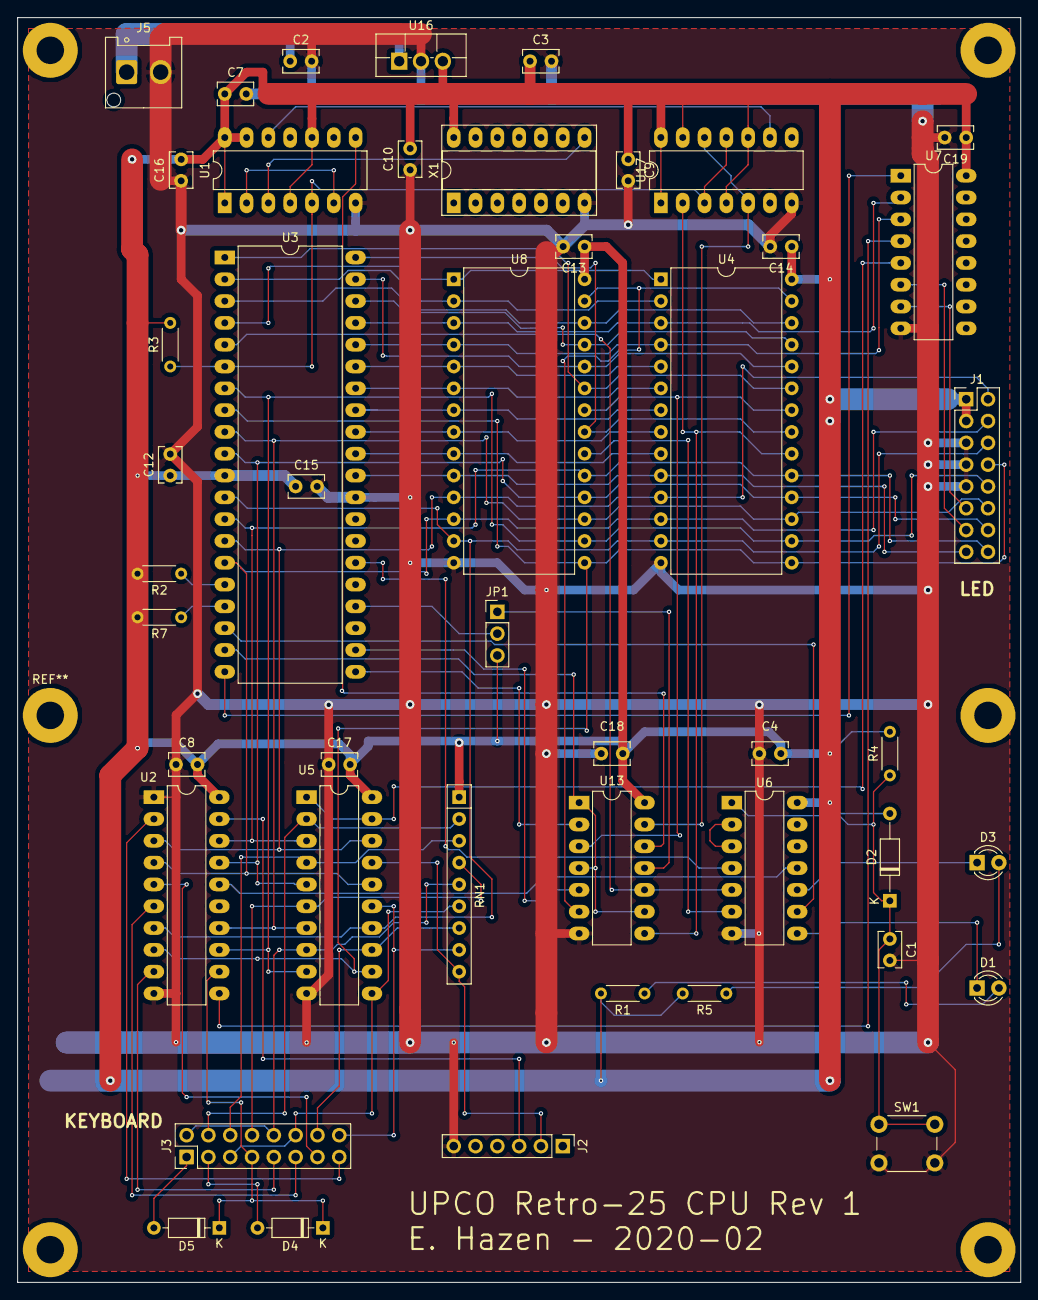
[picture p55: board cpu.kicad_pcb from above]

Board: 2 copper layers, 116.8 x 147.3 mm, 46 parts (0 on the bottom side), 74 nets.

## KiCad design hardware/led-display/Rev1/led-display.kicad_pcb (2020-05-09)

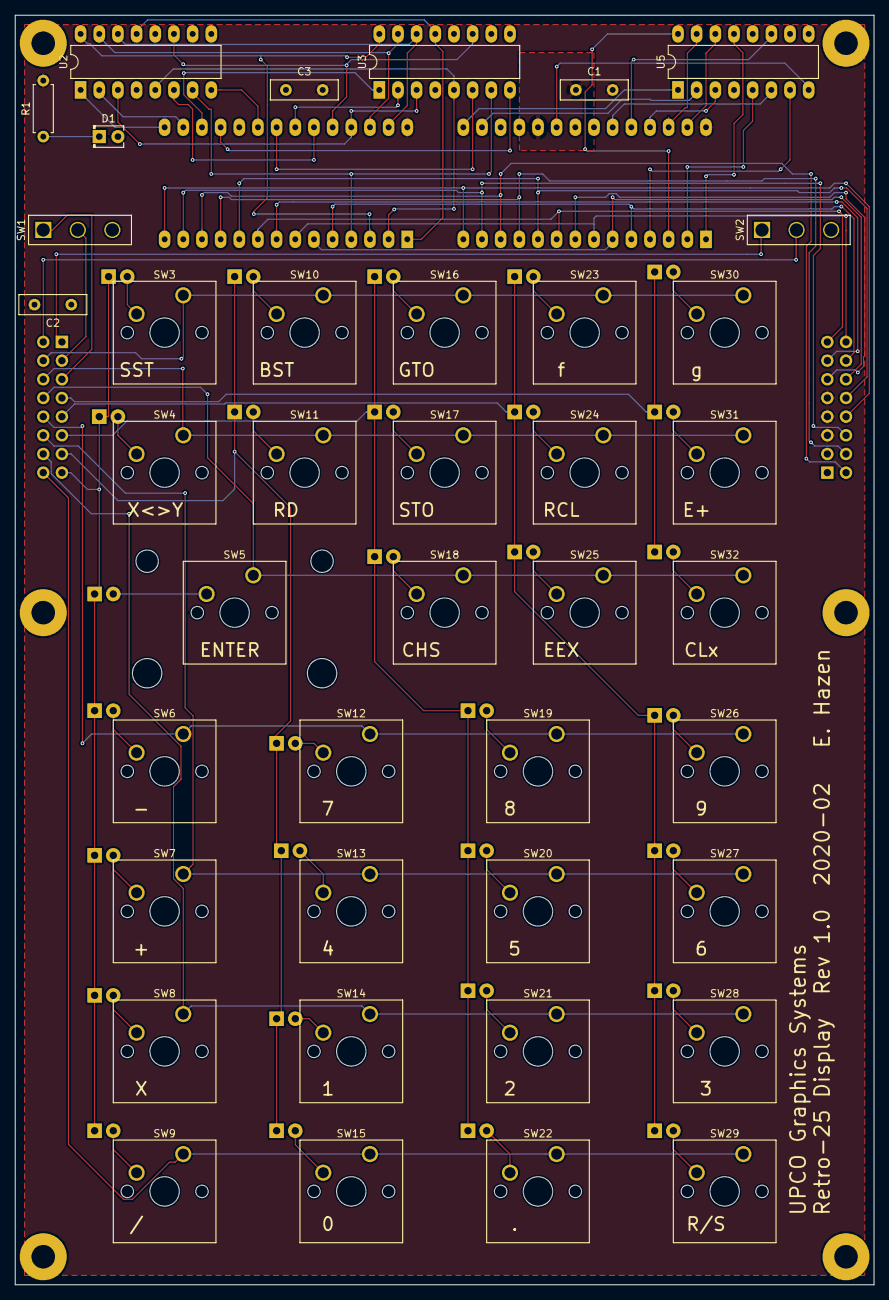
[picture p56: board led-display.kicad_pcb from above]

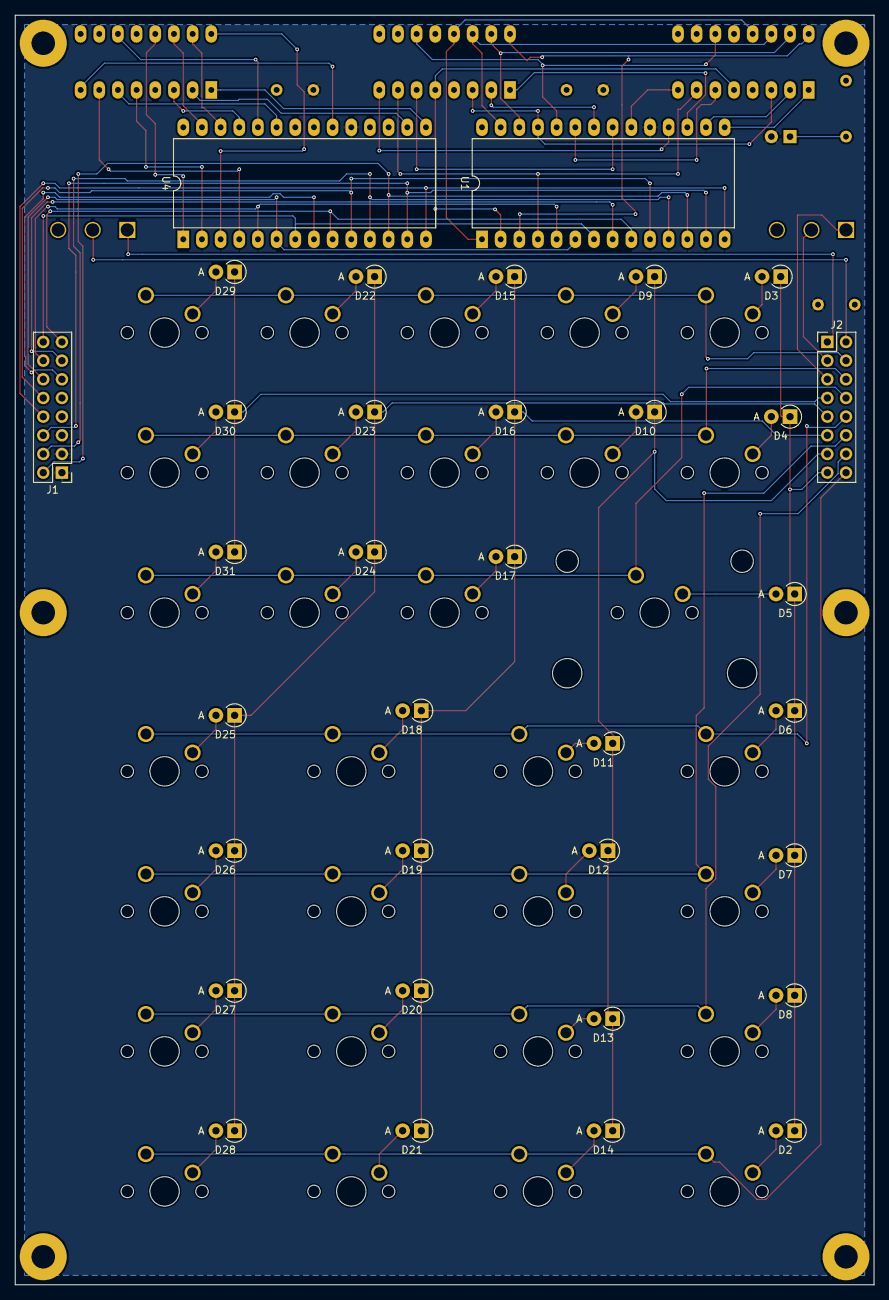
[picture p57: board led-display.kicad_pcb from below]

Board: 2 copper layers, 116.8 x 172.7 mm, 74 parts (34 on the bottom side), 88 nets.

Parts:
C1, C2, C3: 0.1uF; C_Disc_D9.0mm_W2.5mm_P5.00mm
D1: LED; LED_D2.0mm_W4.0mm_H2.8mm_FlatTop
D2, D3, D4, D5, D6, D7, D8, D9, D10, D11, D12, D13, D14, D15, D16, D17, D18, D19, D20, D21, D22, D23, D24, D25, D26, D27, D28, D29, D30, D31: 1N914; D_T-1_P2.54mm_Vertical_AnodeUp
J1, J2: C2x8100; PinHeader_2x08_P2.54mm_Vertical
R1: 470; R_Axial_DIN0207_L6.3mm_D2.5mm_P7.62mm_Horizontal
SW1, SW2: SW_SPST; sw_slide_4.7mm
SW3, SW4, SW6, SW7, SW8, SW9, SW10, SW11, SW12, SW13, SW14, SW15, SW16, SW17, SW18, SW19, SW20, SW21, SW22, SW23, SW24, SW25, SW26, SW27, SW28, SW29, SW30, SW31, SW32: MX1A-C1NW; SW_Cherry_MX1A_1.00u_PCB
SW5: MX1A-C1NW; SW_Cherry_MX1A_2.00u_PCB
U1, U4: ICM7218A; DIP-28_W15.24mm_LongPads
U2, U3, U5: LTC-4627JR; DIP-16_W7.62mm_LongPads

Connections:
/D0: J1.2, U1.12, U4.12
/D1: J1.4, U1.11, U4.11
/D2: J1.6, U1.13, U4.13
/D3: J1.8, U1.14, U4.14
/D4: J1.10, U1.10, U4.10
/D5: J1.12, U1.6, U4.6
/D6: J1.14, U1.5, U4.5
/D7: J1.16, U1.7, U4.7
/MODE: J1.15, U1.9, U4.9
/WR2: J1.11, U4.8
GND: C1.2, C2.2, C3.2, J1.5, J1.7, J1.9, R1.2, U1.28, U4.28
unnamed: D1.1, R1.1
unnamed: D2.1, D3.1, D4.1, D5.1, D6.1, D7.1, D8.1, J2.15
unnamed: D2.2, SW9.2
unnamed: D3.2, SW3.2
unnamed: D4.2, SW4.2
unnamed: D5.2, SW5.2
unnamed: D6.2, SW6.2
unnamed: D7.2, SW7.2
unnamed: D8.2, SW8.2
unnamed: D9.2, SW10.2
unnamed: D9.1, D10.1, D11.1, D12.1, D13.1, D14.1, J2.13
unnamed: D10.2, SW11.2
unnamed: D11.2, SW12.2
unnamed: D12.2, SW13.2
unnamed: D13.2, SW14.2
unnamed: D14.2, SW15.2
unnamed: D15.1, D16.1, D17.1, D18.1, D19.1, D20.1, D21.1, J2.11
unnamed: D15.2, SW16.2
unnamed: D16.2, SW17.2
unnamed: D17.2, SW18.2
unnamed: D18.2, SW19.2
unnamed: D19.2, SW20.2
unnamed: D20.2, SW21.2
unnamed: D21.2, SW22.2
unnamed: D22.1, D23.1, D24.1, D25.1, D26.1, D27.1, D28.1, J2.9
unnamed: D22.2, SW23.2
unnamed: D23.2, SW24.2
unnamed: D24.2, SW25.2
unnamed: D25.2, SW26.2
unnamed: D26.2, SW27.2
unnamed: D27.2, SW28.2
unnamed: D28.2, SW29.2
unnamed: D29.1, D30.1, D31.1, J2.7
unnamed: D29.2, SW30.2
unnamed: D30.2, SW31.2
unnamed: D31.2, SW32.2
unnamed: J1.13, U1.8
unnamed: J2.1, SW2.1
unnamed: J2.2, SW2.2
unnamed: J2.3, SW1.2
unnamed: J2.4, SW3.1, SW10.1, SW16.1, SW23.1, SW30.1
unnamed: J2.5, SW1.1
unnamed: J2.6, SW4.1, SW11.1, SW17.1, SW24.1, SW31.1
unnamed: J2.8, SW5.1, SW18.1, SW25.1, SW32.1
unnamed: J2.10, SW6.1, SW12.1, SW19.1, SW26.1
unnamed: J2.12, SW7.1, SW13.1, SW20.1, SW27.1
unnamed: J2.14, SW8.1, SW14.1, SW21.1, SW28.1
unnamed: J2.16, SW9.1, SW15.1, SW22.1, SW29.1
unnamed: U1.1, U2.13, U3.13
unnamed: U1.2, U2.5, U3.5
unnamed: U1.3, U2.16, U3.16
unnamed: U1.4, U2.7, U3.7
unnamed: U1.15, U2.1
unnamed: U1.16, U2.2
unnamed: U1.17, U3.1
unnamed: U1.18, U3.8
unnamed: U1.20, U2.8
unnamed: U1.21, U3.6
unnamed: U1.22, U3.2
unnamed: U1.23, U2.6
unnamed: U1.24, U2.11, U3.11
unnamed: U1.25, U2.3, U3.3
unnamed: U1.26, U2.15, U3.15
unnamed: U1.27, U2.14, U3.14
unnamed: U4.1, U5.13
unnamed: U4.2, U5.5
unnamed: U4.3, U5.16
unnamed: U4.4, U5.7
unnamed: U4.15, U5.1
unnamed: U4.16, U5.2
unnamed: U4.20, U5.8
unnamed: U4.23, U5.6
unnamed: U4.24, U5.11
unnamed: U4.25, U5.3
unnamed: U4.26, U5.15
unnamed: U4.27, U5.14
VCC: C1.1, C2.1, C3.1, D1.2, J1.1, J1.3, U1.19, U4.19

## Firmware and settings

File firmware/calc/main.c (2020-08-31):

/*

Eric Hazen May 2020

Based on Eric Smith's work, and Chris Chung's "Nonpariel Physical"

$Id: proc_woodstock.h 686 2005-05-26 09:06:45Z eric $
Copyright 1995, 2003, 2004, 2005 Eric L. Smith <eric@brouhaha.com>

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
You should have received a copy of the GNU General Public License
along with this program (in the file "COPYING"); if not, write to the
Free Software Foundation, Inc., 59 Temple Place - Suite 330, Boston,
MA 02111, USA.
*/


//
// This is the main program for the Retro-25 calculator
// 

#include <stdbool.h>
#include <stdint.h>
#include <stdio.h>
#include <stdlib.h>
#include <string.h>
#include <ctype.h>

#include <z80.h>

#include "diskey.h"
#include "key_translate.h"
#include "vfd_control.h"

// not sure if this is right, since we only support the 25C,
// but extra RAM won't hurt
#define __USE_RAM	32	// our highest model 33c has 32 units

// flag to turn display on and off with "power" switch
// or timeout
static int last_display_enable = 1;
static int global_display_enable = 1;

// timeout counter for display blanking... clock is ~ 3kHz
// this should be about 10 min
#define DISPLAY_TIMEOUT (60L*10*3000)
// 10s for testing
// #define DISPLAY_TIMEOUT (10L*3000)

static uint32_t display_timeout;

#include "rom_25.h"

// for historical reasons most of the code is in here...
#include "np25_hack_standalone.h"

#ifdef UMON_SERVER
void umon_crlf() {
  umon_putc( '\r');
  umon_putc( '\n');	  
}

// receive char as hex
uint8_t umon_tohex1( uint8_t ch) {
  if( isdigit(ch))
    return ch-'0';
  else if( isxdigit(ch))
    return toupper(ch)-'A'+10;
  else
    return 0;
}

// read 4 hex characters
uint16_t umon_ghex4() {
  uint16_t v = 0;
  for( uint8_t i=0; i<4; i++)
    v = (v << 4) | umon_tohex1( umon_getc());
  return v;
}

// send low nibble as hex character
void umon_phex1( uint8_t v) {
  v &= 15;
  if( v < 10)
    umon_putc( v + '0');
  else
    umon_putc( v - 10 + 'A');
}

// send 16-bit hex value
void umon_phex4( uint16_t v) {
  umon_phex1( (v >> 12));
  umon_phex1( (v >> 8));
  umon_phex1( (v >> 4));
  umon_phex1( v);
}

// some info to help locate things in assembly
struct {
  uint16_t jump_to;		/* UMON jump address 0x8121 */
  uint16_t jump_back;		/* return address filled in by assembly */
  uint16_t regs;		/* address of registers */
  uint16_t ram;			/* address of RAM */
} reg_info;
#endif

static volatile uint8_t _pgm_run=1;

  //________________________________________________________________________________
int main() {

#define RAM_OFFSET	(7*9)
#define RAM_SIZE	(7*7)		// 49 program steps

  woodstock_clear_memory();
  woodstock_set_rom( 2);
  woodstock_new_processor();

  uint8_t done=0;
  uint8_t c=0;
  uint8_t release_in=0;
  uint16_t key=0;

  uint16_t switches;
  uint16_t last_sw;

  uint16_t chr;
  unsigned char *adrs;
  uint8_t nregs;
  uint8_t rw;
  uint8_t stop;

  woodstock_set_ext_flag (3, _pgm_run);		// set run mode

#ifdef UMON_SERVER
  reg_info.jump_to = 0x8103;	/* UMON breakpoint entry */
  reg_info.jump_back = 0x9000;
  reg_info.regs = (uint16_t) & _act_reg;
  reg_info.ram = (uint16_t) & _act_reg.ram;
#endif
  
  // initialize hardware
#ifdef VFD
  vfd_power_up();
#endif  

  while(1) {
    if( umon_serial()) {	/* check for serial action (break) */
      while( umon_serial())	/* wait for break to end */
	;
#ifdef UMON_SERVER
      umon_putc( '>');		/* send a prompt */
      chr = umon_getc();
      umon_putc( chr);		/* echo char */
      rw = 0;			/* default:  read */
      stop = 0;			/* flag to exit loops */
      nregs = 8;		/* default number of registers */
      adrs = 0;			/* default: invalid address */
      /*
       * commands:  S,R,P  - read stack, regs, program
       *              M,Q  - write regs, program
       */
      switch( toupper( chr)) {
      case 0x91:		/* reboot to EEPROM */
	reg_info.jump_to = 0;
	umon_jump( (uint16_t) &reg_info);
	break;
      case 'J':
	umon_jump( (uint16_t) &reg_info);	/* jump to umon state saver */
	break;
      case 'I':			/* get addresses */
	umon_phex4( (uint16_t) &_act_reg);
	umon_crlf();
	umon_phex4( (uint16_t) &_act_reg.ram);
	umon_crlf();
	umon_phex4( (uint16_t) &_act_reg.ram + 14*9);
	umon_crlf();
	break;
      case 'S':			/* read stack */
	adrs = (unsigned char *) &_act_reg;
	break;
      case 'M':			/* write memories */
	rw = 1;
      case 'R':			/* read memories */
	adrs = (unsigned char *) &_act_reg.ram;
	break;
      case 'Q':			/* write PGM */
	rw = 1;
      case 'P':			/* read PGM */
	nregs = 7;		/* PGM is only 7 regs */
	adrs = (unsigned char *) &_act_reg.ram + 14*9;
      }

      if( adrs) {
	for( uint8_t i=0; i<nregs; i++) {
	  adrs += 14;
	  for( uint8_t k=0; k<14; k++) {
	    --adrs;
	    if( rw) {		/* writing */
	      chr = umon_getc(); /* get a char */
	      umon_putc( chr);	 /* echo back */
	      if( iscntrl(chr)) { /* bail out if control */
		stop = 1;
		break;
	      } else {		/* cvt from hex and write */
		*adrs = umon_tohex1( chr);
	      }
	    } else {		/* reading */
	      umon_phex1( *adrs);
	    }
	  }
	  adrs += 14;
	  if( !rw) umon_crlf();
	  if( stop) break;
	}
	umon_putc( '$');
      } else {
	umon_putc( '?');
      }
#endif      

    }

    key = umon_kbscan();
    
    if( key)
      woodstock_press_key( translate_key(key & 0xff));
    else
      woodstock_release_key();
    

    switches = umon_switches();

    // handle PGM/RUN switch
    woodstock_set_ext_flag (3, switches & 1);

    // manage display with power switch and timeout
    // if the switch is off, keep the display off
    
    if( !(switches & 2)) {	// power sw set to "off"
      global_display_enable = 0;
      display_timeout = 0;
    } else {			// power sw set to "on"
      if( key)			// reset timeout on key press
	display_timeout = 0;
      if( display_timeout == DISPLAY_TIMEOUT) {
	global_display_enable = 0;
      } else {
	global_display_enable = 1;
	++display_timeout;
      }
      // if power sw just turned on, reset timeout
      if( !(last_sw & 2))
	display_timeout = 0;
    }

    // handle display blanking

#ifdef VFD
    // see if display state changed
    if( global_display_enable != last_display_enable) {
      if( global_display_enable)
	vfd_power_up();
      else
	vfd_power_down();
    }
#else	
    // blank display here if it just turned off
    if( !global_display_enable && last_display_enable)
      umon_blank();
#endif
    
    last_display_enable = global_display_enable;
    last_sw = switches;

    if (!woodstock_execute_instruction()) break;

  }
  return 0;

}

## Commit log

2020-05-09 Upload Rev A/1 Hardware Files
    [cpu-B.Cu.gbr, cpu-B.Mask.gbr, cpu-Edge.Cuts.gbr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]
2020-05-27 add assembler, loader
2020-07-01 Initial schem for VFD display
    [vfd-display.kicad_pcb, vfd-display.sch]
2020-07-01 Preliminary VFD schematic
    [vfd-display.sch]
2020-07-02 Schematic, footprints, partial placement
    [vfd-display.kicad_pcb, vfd-display.sch]
2020-07-02 tweak placement
    [vfd-display.kicad_pcb]
2020-07-03 Rev 1 design for fab
    [vfd-display-B_Cu.gbr, vfd-display-B_Mask.gbr, vfd-display-B_SilkS.gbr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]
2020-07-03 rev 1 gerber zip
    [vfd-display-NPTH.drl]
2020-07-03 add 3D model for tubes
    [tube.scad, vfd-display.kicad_pcb]
2020-07-09 add BOMs
    [to_order.ods, vfd-display.ods]
2020-07-10 VFD board photo
2020-07-29 Update schematic PDF
    [vfd-display.sch]
2020-08-03 VFD display now assembles...
2020-08-06 mech dwgs
    [bottom_plate.dxf, keyboard_plate2.dxf, side_view.dxf]
2020-08-07 DXF for case
    [all_parts.dxf, back.dxf, front.dxf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]
2020-08-13 Update Makefile for VFD/LED targets
2020-08-14 cleaning up
    [back.dxf, bottom_plate.dxf, front.dxf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]
2020-08-14 add PSU
    [psu.kicad_pcb, psu.sch]
2020-08-14 ordered PCBs
    [psu-B_Cu.gbr, psu-B_Mask.gbr, psu-B_SilkS.gbr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]
2020-08-29 resistor values
    [psu.sch]
2020-08-29 Power supply control
2020-08-31 fix bugs in bootloader, make umon base control by makefile
    [cpu.sch]
2020-10-27 add current hex files
2021-02-05 add linear regression program, add R/S to assembler
2021-02-05 remove assembler output on make clean
2025-02-19 tweak the keyboard plate
    [keyboard_plate3.dxf]

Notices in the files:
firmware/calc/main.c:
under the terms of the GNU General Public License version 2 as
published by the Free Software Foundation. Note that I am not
